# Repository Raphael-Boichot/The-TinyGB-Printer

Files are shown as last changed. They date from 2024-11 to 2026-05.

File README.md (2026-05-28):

# The TinyGB Printer - A standalone Game Boy Printer emulator with a fancy display

The TinyGB Printer is the simplest possible Game Boy printer emulator storing images directly on SD card. This is basically a demake of the ESP32 based [NeoGB printer](https://github.com/zenaro147/NeoGB-Printer) (which I co-developed with [Rafael Zenaro](https://github.com/zenaror), based on the emulator platform casted by [Brian Khuu](https://github.com/mofosyne)), but for the Raspberry Pi Pico. It stores the printed images in pixel perfect 4x PNG format. It is meant to be powered by double NiMH AA or AAA batteries, like the Game Boy Color / Pocket, so that you can recharge them with the same equipment. All parts are cheap and easy to gather online and assembly is meant to be simplistic.

**It supports all printing modes of all games compatible with the Game Boy Printer (with all possible protocol tricks like double speed, compression, custom palette, break command, arbitrary lenght printing, etc.).** So yes, all Pokémons, Link's Awakening DX, Super Mario Bros Deluxe, Game Boy Camera, all work, plus dozens of other ones. This emulator of course works with any genuine model of Game Boy (DMG, GBC, GBP, GBA). Compatibility was also confirmed with the third-party [GB Boy Colour](https://github.com/Raphael-Boichot/Knowledge-repo-about-the-Kong-Feng-GB-BOY-COLOUR) and Analogue Pocket devices.

You can copy, modify, or improve it as you wish, all sources are provided. **Just respect the license and the dedication of the authors**. In very brief, don't forget to cite Brian KHUU (emulator/parser part) and Raphaël BOICHOT (hardware/decoder part) as authors and give a link to this repository.

You can also share your images with the friendly community of Game Boy Camera enthusiasts on the [Game Boy Camera Club Telegram](https://t.me/gameboycamera). I can also help you solving issues on that Telegram. Just to precise: I do not sell the device, buying parts, making and sending them at a decent price would not cover my working hours.

## Make it, enjoy it !
**Nothing to compile, nothing to install, drop the UF2 file to the device and it works straight after soldering.**
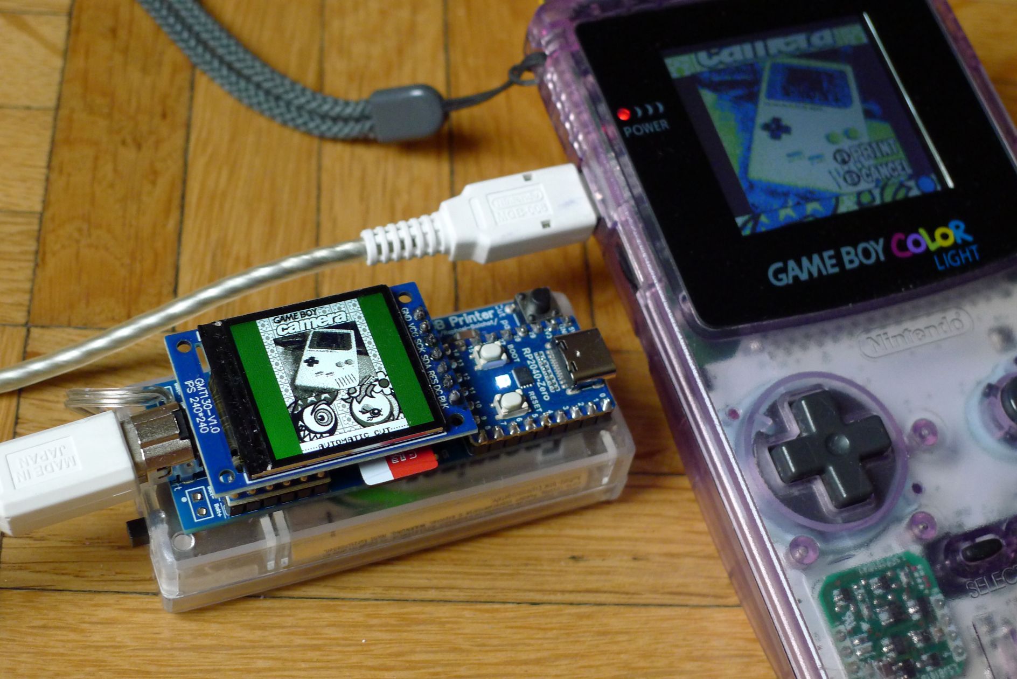
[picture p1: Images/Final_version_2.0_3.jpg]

(Credit: Raphaël BOICHOT)

## What's inside / how does it work ?
The code is basically the [Arduino Game Boy Printer emulator](https://github.com/mofosyne/arduino-gameboy-printer-emulator) (with a bit of tuning to handle the Pi Pico SDK commands) running on core 0 and a custom image decoder running on core 1 in parallel. Good timing between the two cores is critical (and required quite a lot of optimisation) as core 0 cannot miss any single interrupt while core 1 must fulfill all its tasks on time with a good safety margin. Flux control to "occupy" the Game Boy during image conversion is not necessary here.

## Easy to install
- After soldering everything, connect the Raspberry Pi Pico with a USB cable to your computer while pressing BOOT, drop the [uf2 file](/Builds) to the USB folder poping out and enjoy your device. If it makes smoke, check for shorts with a multimeter.
- **Only** if you want to modify the code and recompile it, use the [Arduino IDE](https://www.arduino.cc/en/software) equipped with the [RP2040 core for Arduino IDE](https://github.com/earlephilhower/arduino-pico). Then from the Arduino library manager install the [PNGEnc library](https://github.com/bitbank2/PNGenc), the [Bodmer TFT_eSPI libray](https://github.com/Bodmer/TFT_eSPI) and the [Adafruit Neopixel for Arduino IDE](https://github.com/adafruit/Adafruit_NeoPixel), [configure libraries](/TinyGB_Printer/TFT_setup) and choose the Raspberry Pi Pico target before compiling with default parameters (@200 MHz). I used the Arduino IDE because it gives a very user-friendly access to dev on RP2040 core without too much limitations. And the Earle Philhower RP2040 core is damn good too, it contains everything you need, tons of commented examples and ultra reactive support.

## Easy to use
- 🟢 Power the device without touching anything, the LED flashes green (display backround is green too), images are recorded and sliced automatically, this is the **automatic mode**. This is perfect for the Game Boy Camera for example. Multi-print is of course supported. It uses protocol after margins to decide wether an image is finished or not.
- 🔵 Power while pressing the pushbutton : the LED flashes blue (display backround is blue too), all images are stacked together in a single file until you press the pushbutton again to "cut paper", it's the **tear mode**. Some rare games require this (see complete game list). You can also use it freely to stack images in some other games. Just be creative !
- :red_circle: Power the device and the LED blinks red on and off in cycle: SD card not connected or not formatted in FAT32. SD card can be inserted during this step, the device will then boot normally.
- :repeat: Cycling the power switch on the battery box or using the RESET button on the board has the same effect (reset printer state and increase folder number with the regular build).

A new folder is created at each boot/RESET. Each image file has a unique ID. Flashes during printing indicate flux of data and access to SD card. Color of flashes indicates the mode (green for automatic mode, blue for tear mode). White dim LED indicates that the device is idle and ready to receive data (and that you forgot to switch it off after printing), in case you chose not using the display.

If you miss the analog feeling of thermal paper, you can still use this [thermal printer emulator](/SD/Paper_emulator) written in GNU Octave which turns your pixel perfect images into noisy paper strips with an exact aspect ratio and paper tone compared to a real Game Boy Printer equiped with genuine color / white paper. At least these will not fade with time !

**There is also an easter egg, will you find it ?** (Easy for real camera / printer nerds)

## Easy to fabricate
All the parts used here are cheap and easy to find on Aliexpress. You probably yet have some leftovers from other projects. The total price is probably well below 15€ per unit (being pessimistic), shipping of parts included, and you will have extra parts to gift some to your nerdy friends.

**Parts to order:**
- [The PCB](/PCB_2.0_with_TFT/). Order at [JLCPCB.com](https://jlcpcb.com/) (just drop the gerber .zip to the site and use default options). VAT is paid when ordering so no bad surprise for European customers. They also offer worldwide very cheap shipping options. The PCB was designed with [EasyEDA Standard Edition](https://easyeda.com/) if you want to modify something.

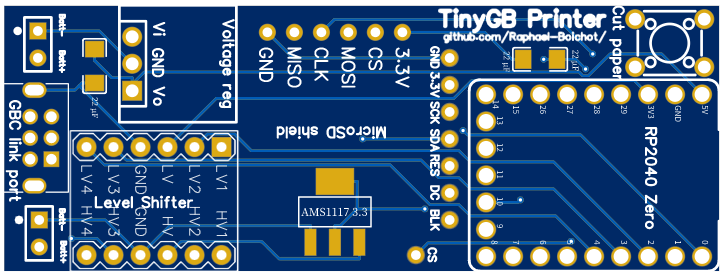
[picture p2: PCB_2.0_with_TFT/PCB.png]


(note the TFT CS pin exposed, just in case, but not used with the display listed next)

The code works with the two PCB versions (1.0 without TFT and 2.0 with TFT) but I recommend ordering only the 2.0 even if you do not plan using the TFT display (just let the pins exposed or soldered with a bare female pin header).

- [A Raspberry Pi Pico Zero](https://aliexpress.com/item/1005007945758255.html). Just check pinout if seller is not the same.
- [A bare MicroSD shield](https://www.aliexpress.com/item/1005005302035188.html) without internal power converter and **without pin header** (the pins header will be mounted upside down compared to pre-soldered units so it must be soldered manually).
- [A 240x240 1.3 inches TFT Display](https://aliexpress.com/w/wholesale-240x240-pixels-7-pins.html). It must be that exact one, 7 pins, without CS, 240x240 pixels, GMT130-V1.0 (now often IPS 240x240 apparently). If you decide to use another 240x240 pixels model, CS pin is exposed and driven but it's up to you to reconfigure the TFT library if necessary.
- [A 4 gates level shifter](https://www.aliexpress.com/item/1005006255186878.html). The Pi Pico pins are not 5V rated, so the need for a level shifter. They are highly reusable in other pico related projects, so you never have too much of them in spare. If the ones you received [look like this](https://forum.arduino.cc/t/logic-level-shifter-problem/1138650?page=2), ask for refund, they are fake / defective.
- [A 5V DC-DC step-up converter](https://www.aliexpress.com/item/32809095271.html), 0.9-5V (input) to 5V (output). I know, it does not look impressive but it does perfectly the job of powering small devices. If you want the blue fullset, they sometimes appear with blus PCB.
- [Male and female pin headers](https://www.aliexpress.com/item/4000873858801.html) with 2.54 mm spacing, whatever the pin lenght, you will trim them anyway. The female pin header is required for the TFT display only. Once again, highly reusable in other projects.
- [A GBA/GBC external link port](https://www.aliexpress.com/item/1005006358075502.html). They can be cheap or not depending on the seller, do not hesitate to change. This port is for the Gameboy Advance but it's backwards compatible (with the right cable) with any model of Game Boy.
- [A 6x6 mm pushbutton](https://www.aliexpress.com/item/1005003938244847.html), whatever height. The softer the better if you have the choice. Make sure you get the 4 pins version with the short legs.
- [2 x 22 µF caps with a 1206 footprint](https://www.aliexpress.com/item/1005006022131059.html) (22 to 50 µF is OK if you have spares). Take 10V or 16V. These come in packs of 20, you only need 2, so check your drawers just in case.
- An [AMS1117-3.3V converter](https://www.aliexpress.com/item/4001104149446.html) - Beware, take the 3.3V, not the ADJ !
- A [2xAA](https://www.aliexpress.com/item/4000980371784.html) or [2xAAA](https://www.aliexpress.com/item/1005004195965365.html) battery box **with switch** (mandatory, this is the only way to switch the device on and off). Single AA or AAA battery is too weak to power the device reliably. The choice of AA or AAA depends on which is your go to Game Boy (pocket or GBC), in order to recharge batteries by batch of 4.

Additionnaly, you would need a [GBC compatible link cable](https://www.aliexpress.com/item/1005006479007710.html). Beware, purple GBA cables (or specific GBA cables) are not compatible due to a different pinout. You can of course use genuine GBC/GBP link cables or DMG link cable with GBC/GBP adapter.

**How to make it:**
- Solder the pin headers on the Pi Pico, the SD shield, the level shifter and the step-up converter. **Beware of which side you solder the pin header**. Check if you can drop the uf2 file to the Pico, it must blink red on and off, it's normal.
- Solder the caps and the 3.3V converter first. They are surface mount components but big enough to be soldered easily. Don't be afraid by their size. They are not tiny, you're just too far.
- Solder all parts with the minimal clearance possible against the PCB.
- The TFT display can be mounted on female pin headers at this step but display is fully optional. The device works without !
- Trim and reflow all pins on the back side to get a clean finish. I personally trim pins as short as possible before soldering but there is a risk of scratching the solder mask, so be carefull.
- Clean as much as you can any flux residues with isopropanol. Flux may create parasitic noise between pins. **Beware, flushing the TFT display with isopropanol is a very reliable way of killing it !**
- Solder the battery box terminals and stuck the PCB on it with double sided tape for example (or hot glue if you're addicted to hot snot like me).
- You're ready to print !

The device can record a little more than 1 standard Game Boy Camera image for each mAh of battery storage capacity, so about 800 images with 2xAA batteries and about 2500 images with 2xAA batteries on a single charge (TFT display connected). Not connecting the TFT display would allow about 30% more images to be recorded on a single charge.

**The TinyGB Printer assembled without display (TFT display is optional) and 2xAAA battery box**
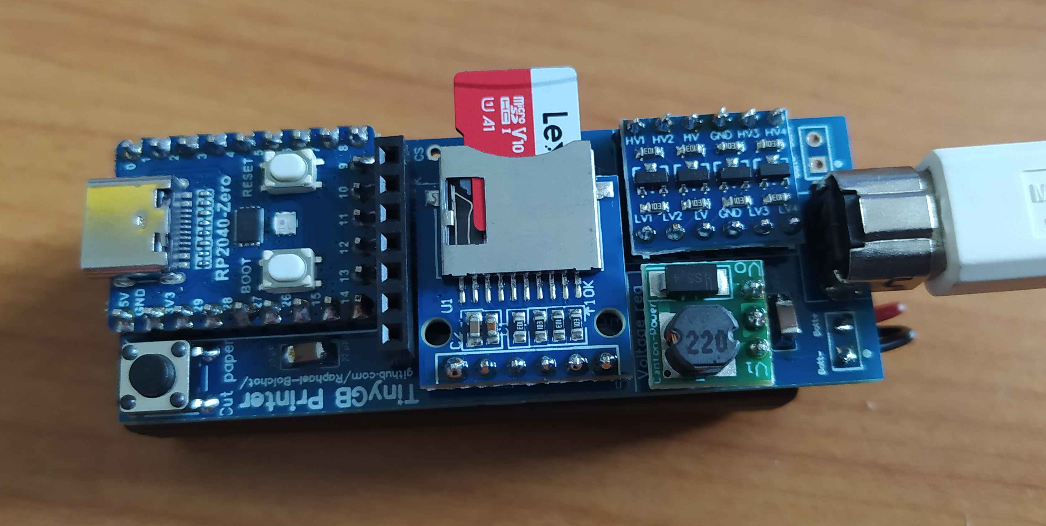
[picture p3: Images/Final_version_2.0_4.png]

(Credit: Raphaël BOICHOT)

**The TinyGB Printer assembled with a 2xAA battery box and the TFT display compared to the 2xAAA / no TFT setup**
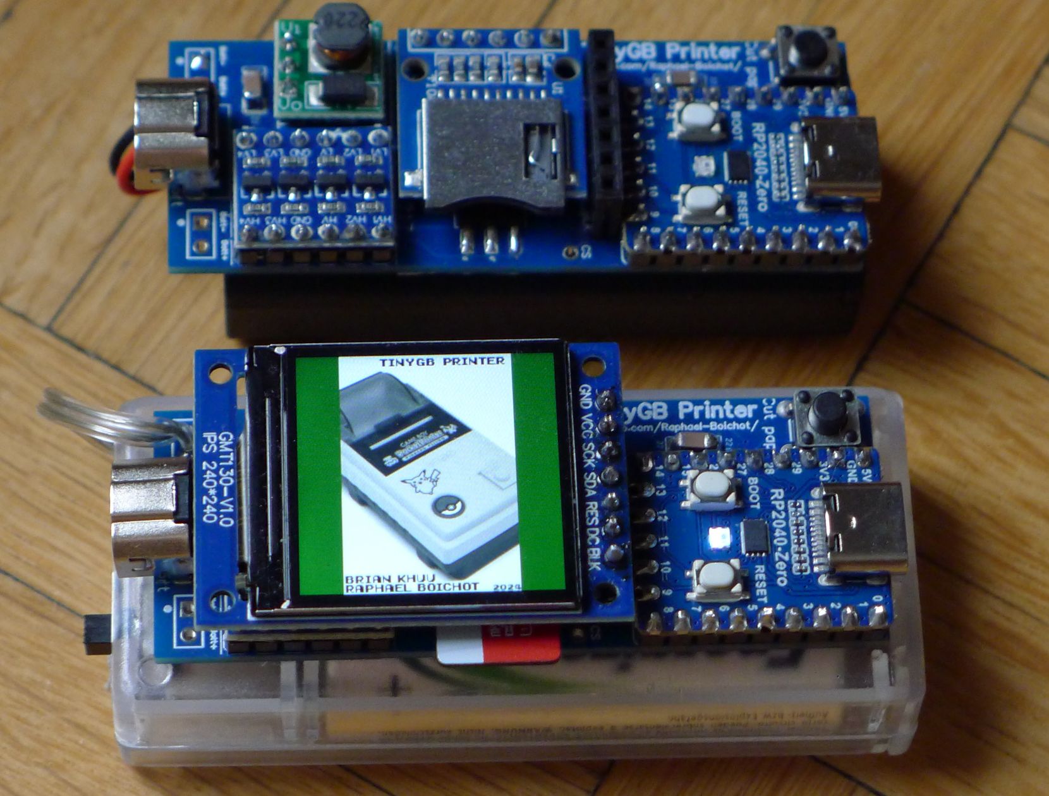
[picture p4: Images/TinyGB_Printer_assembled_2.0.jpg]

(Credit: Raphaël BOICHOT)

**The TinyGB Printer with TFT display and [3D printed case](/PCB_2.0_with_TFT/3D_printed_enclosure)**
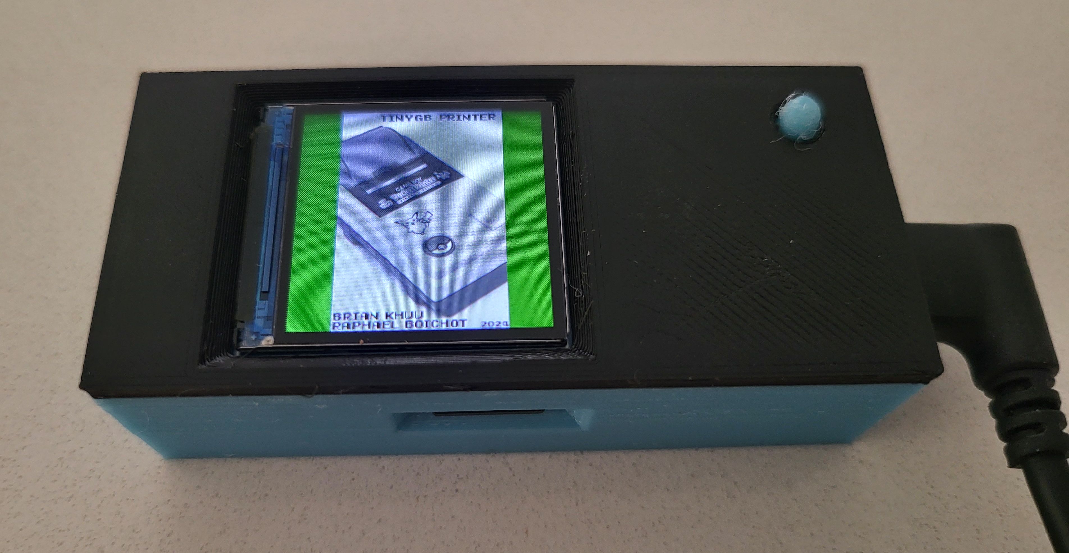
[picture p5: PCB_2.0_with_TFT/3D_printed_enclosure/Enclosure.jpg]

(Credit: Slade1972)

**Troubleshooting**
- Last image is not written or image file is broken ? You've probably switched the device off during the PNG encoding or you forgot to tear paper with the pushbutton in tear mode.
- The TFT display does not work when you compile by yourself ? See [notes](https://github.com/Raphael-Boichot/The-TinyGB-Printer/blob/f55e4003a29216d7775f089cb41b405cfadc126f/TinyGB_Printer/TinyGB_Printer.ino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) for configuring the TFT_eSPI library, you have to manually edit some command for this very particular display.
- Any SD card must work out of the box, even old/slow ones. If the printer is reluctant to recognize yours, use a [low level formatting tool](https://www.sdcard.org/downloads/formatter/) or low level formatting commands like diskpart on Windows. Filesystem must be FAT32.
- The image palette is obviously wrong for a particular game ? Open an issue and I will rapidely find a solution.

## Examples of use

### Save your achievements and diploma
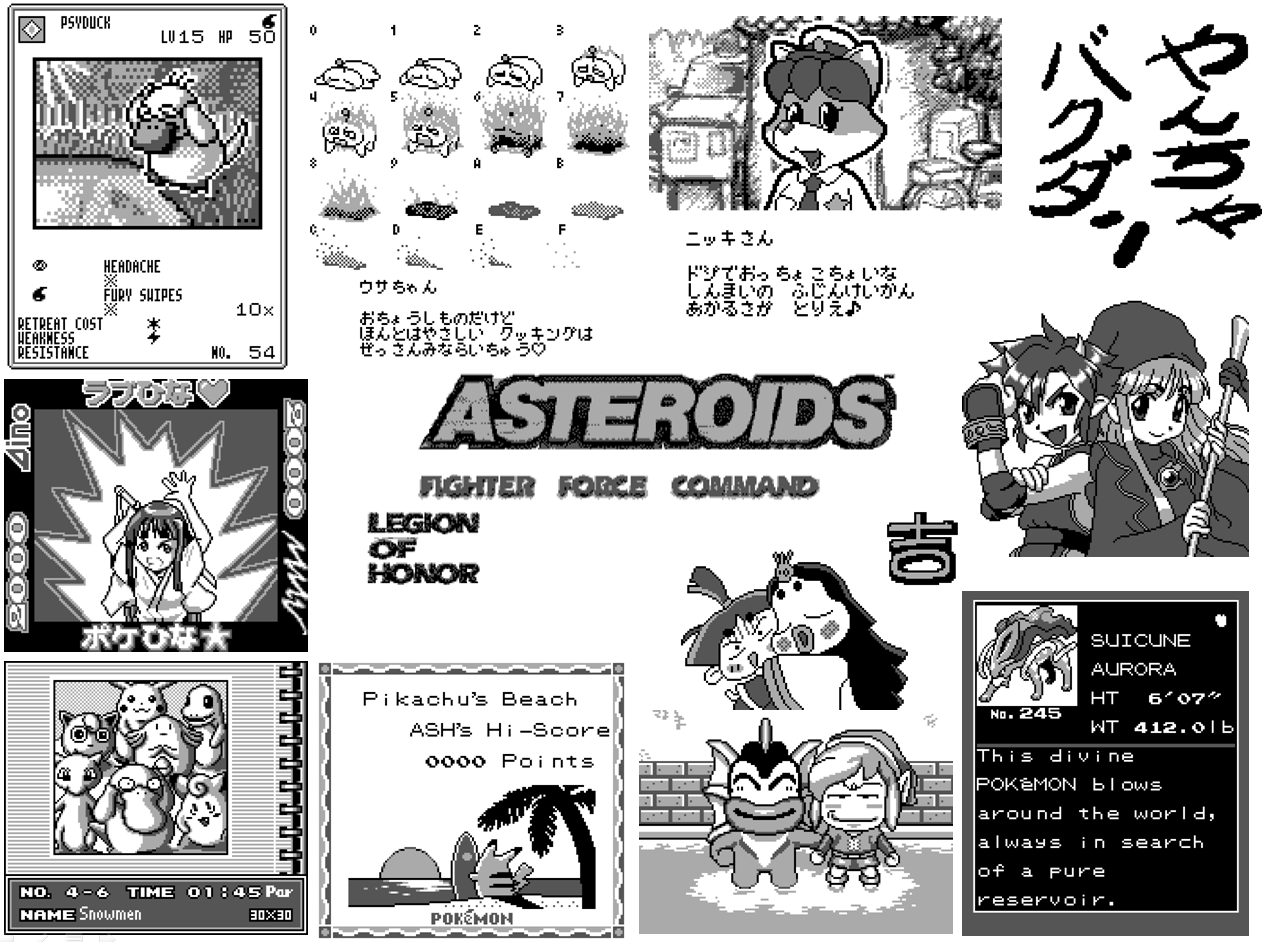
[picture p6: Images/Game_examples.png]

(yes I suck at Surfing Pikachu)

### Save your preferred Game Boy Camera images
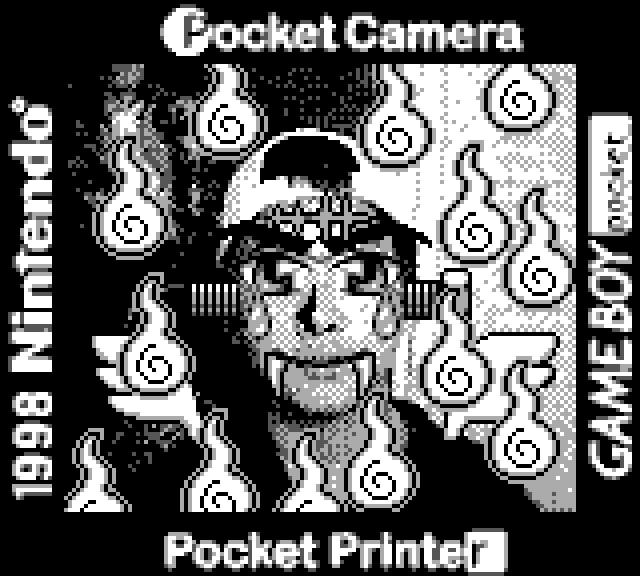
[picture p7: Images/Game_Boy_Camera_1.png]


### Make fancy timelapses with [photo!](https://github.com/untoxa/gb-photo) (requires a [flashable camera](https://github.com/Raphael-Boichot/Game_Boy_Mini_Flashable_Camera) and a [script](/SD/Script_for_animated_gif))


(Credit: Raphaël BOICHOT)

### Make [High Dynamic Range](/SD/Scripts_for_AEB_mode) image with [photo!](https://github.com/untoxa/gb-photo) (requires a [flashable camera](https://github.com/Raphael-Boichot/Game_Boy_Mini_Flashable_Camera))
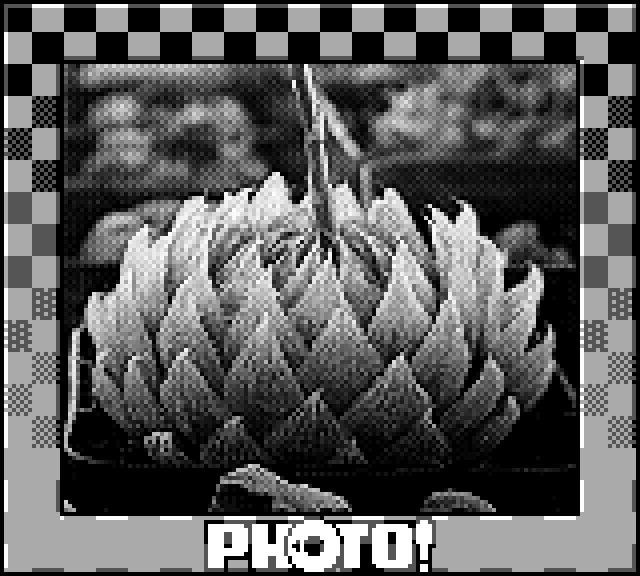
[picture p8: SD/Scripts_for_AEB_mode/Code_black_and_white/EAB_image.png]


(Credit: Raphaël BOICHOT)

### Make color images using RGB filters and [script for stacking](/SD/Scripts_for_AEB_mode) (requires a PC)
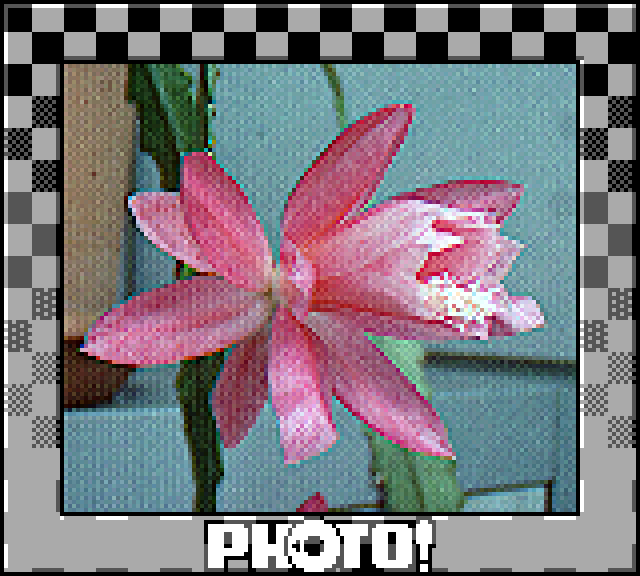
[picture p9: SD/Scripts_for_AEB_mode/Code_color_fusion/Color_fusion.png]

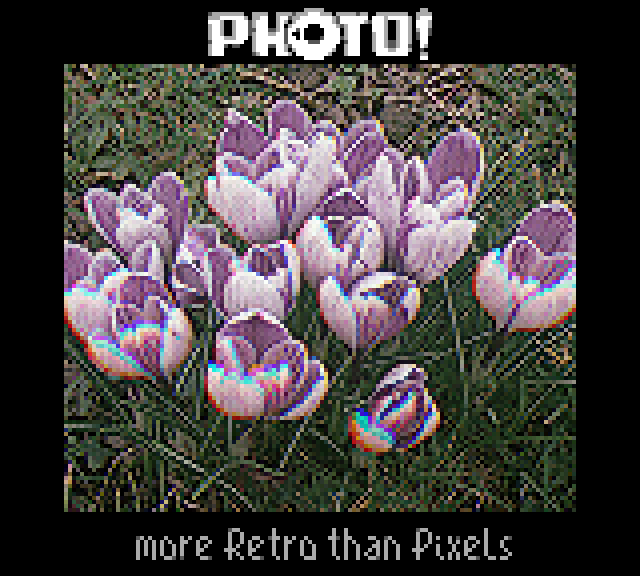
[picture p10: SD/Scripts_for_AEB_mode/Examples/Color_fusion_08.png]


(Yes, this is done with a Game Boy Camera)

Besides scripts proposed here, you can also upload your images to the [GBCamera Android Manager](https://github.com/Mraulio/GBCamera-Android-Manager) or use the [Python HDR image processing tool](https://github.com/seb-tourneux/gbcam-hdr-utils) and apply the exact same process.

### Simulate thermal paper output with a [dedicated script](/SD/Paper_emulator)
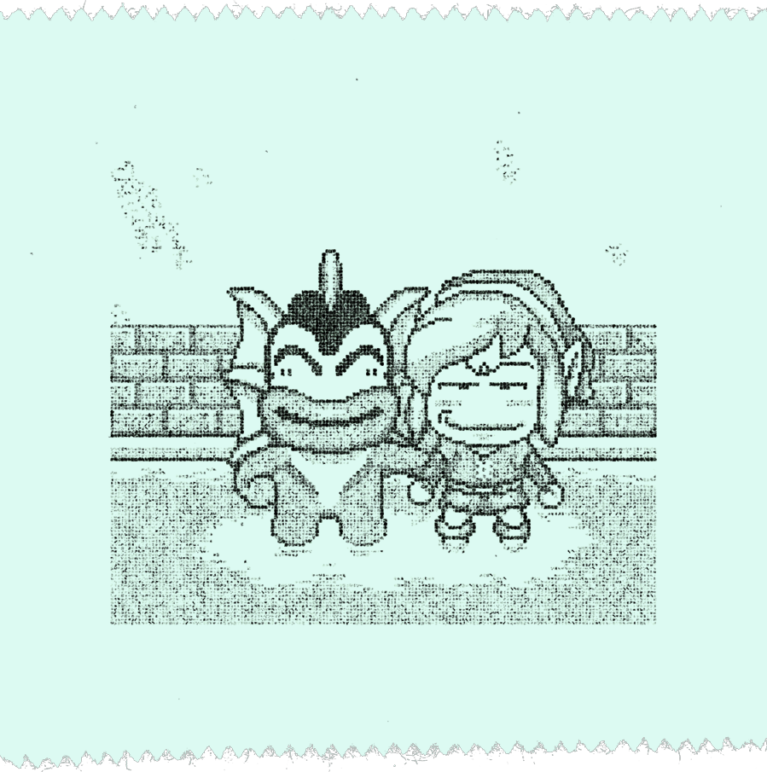
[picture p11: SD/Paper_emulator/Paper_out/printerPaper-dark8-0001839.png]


## Compatible with the 110 original games using the Game Boy Printer
In *Italics* games working fine in automatic mode, in **bold** games requiring the push button to tear paper, or tear mode. For who wonders if I'm crazy, after initially documenting the complete list (I hope) in sweat and blood around 2021, I've tested ALL these games and save hacked several dozens of them to access and test all cryptic printing features, took me months (most are in Japanese, many are [kusoge](https://en.wikipedia.org/wiki/Kusoge)).

- *1942*
- *Alice in Wonderland (US version only, Euro version not printer compatible)*
- *Animal Breeder 3 (あにまるぶりーだー3)*
- *Animal Breeder 4 (あにまるぶり〜だ〜4)*
- *Aqualife (アクアライフ)*
- *Asteroids*
- *Austin Powers: Oh, Behave!*
- *Austin Powers: Welcome to My Underground Lair!*
- *Austin Power Episode 3 - Yeah Baby Yeah (leaked, rom CGBBA3P0.3)*
- *Austin Power Episode 4 - Why Make Millions (leaked, rom CGBBA4P0.0)*
- *Cardcaptor Sakura: Itsumo Sakura-chan to Issho! (カードキャプターさくら 〜いつもさくらちゃんと一緒〜)*
- *Cardcaptor Sakura: Tomoe Shōgakkō Daiundōkai (カードキャプターさくら 〜友枝小学校大運動会〜)*
- *Chee-Chai Alien (ちっちゃいエイリアン)*
- *Cross Hunter - Monster Hunter Version (クロスハンター モンスター・ハンター・バージョン)*
- *Cross Hunter - Treasure Hunter (クロスハンター トレジャー・ハンター・バージョン)*
- *Cross Hunter - X Hunter Version (クロスハンター エックス・ハンター・バージョン)*
- *Daa! Daa! Daa! Totsuzen ★ Card de Battle de Uranai de!? (だぁ!だぁ!だぁ! とつぜん★カードでバトルで占いで!?)*
- *Daikaijuu Monogatari: The Miracle of the Zone II (大貝獣物語 ザ・ミラクル オブ ザ・ゾーンII)*
- *Dejiko no Mahjong Party (でじこの麻雀パーティー)*
- *Densha de GO! 2 (電車でGO!2)*
- *Dino Breeder 3 - Gaia Fukkatsu (ディノブリーダー3 〜ガイア復活〜)*
- *Disney's Dinosaur*
- *Disney's Tarzan (ディズニーズ ターザン) - The game has a palette error fixed by the printer*
- *Donkey Kong Country (ドンキーコング2001)*
- *Doraemon Kart 2 (ドラえもんカート2)*
- *Doraemon Memories - Nobita no Omoide Daibouken (ドラえもんメモリーズ のび太の想い出大冒険)*
- *Doraemon no Game Boy de Asobouyo Deluxe 10 (ドラえもんのGBであそぼうよ デラックス10)*
- *Doraemon no Quiz Boy (ドラえもんのクイズボーイ)*
- *Dungeon Savior (ダンジョンセイバー)*
- **E.T.: Digital Companion**
- *Fairy Kitty no Kaiun Jiten: Yousei no Kuni no Uranai Shugyou (フェアリーキティの開運辞典 妖精の国の占い修行)*
- *Fisher-Price Rescue Heroes: Fire Frenzy*
- *Game Boy Camera or Pocket Camera (ポケットカメラ)*
- *Golf Ou: The King of Golf (ゴルフ王)*
- *Hamster Club (ハムスター倶楽部)*
- *Hamster Paradise (ハムスターパラダイス)*
- *Hamster Paradise 2 (ハムスターパラダイス2)*
- *Harvest Moon 2 (牧場物語GB2)*
- *Hello Kitty no Beads Koubou (ハローキティのビーズ工房)*
- *Hello Kitty no Magical Museum (ハローキティのマジカルミュージアム)*
- *Hello Kitty Pocket Camera (ハローキティのポケットカメラ, leaked, rom GBDHKAJ0.2)*
- *Jinsei Game Tomodachi takusan Tsukurou Yo! (人生ゲーム 友達たくさんつくろうよ!)*
- *Kakurenbo Battle Monster Tactics (モンスタータクティクス)*
- *Kanji Boy (漢字BOY)*
- *Karamuchou wa Oosawagi!: Porinkiis to Okashina Nakamatachi (カラムー町は大さわぎ! 〜ポリンキーズとおかしな仲間たち〜)*
- *Karamuchou wa Oosawagi!: Okawari! (カラムー町は大さわぎ！おかわりっ！)*
- *Kaseki Sousei Reborn II: Monster Digger (化石創世リボーン2 〜モンスターティガー〜)*
- *Kettou Transformers Beast Wars - Beast Senshi Saikyou Ketteisen (決闘トランスフォーマービーストウォーズ ビースト戦士最強決定戦)*
- *Kidou Senkan Nadesico - Ruri Ruri Mahjong (機動戦艦ナデシコ ルリルリ麻雀)*
- *Kisekae Monogatari (きせかえ物語)*
- *Klax*
- *Konchuu Hakase 2 (昆虫博士2)*
- *Little Nicky*
- *Logical*
- *Love Hina Pocket (ラブ ひな)*
- *Magical Drop*
- **Mary-Kate and Ashley Pocket Planner**
- **McDonald's Monogatari : Honobono Tenchou Ikusei Game (マクドナルド物語)**
- *Mickey's Racing Adventure*
- *Mickey's Speedway USA*
- *Mission: Impossible*
- *Monster ★ Race 2 (もんすたあ★レース2)*
- *Monster ★ Race Okawari (もんすたあ★レース おかわり)*
- *Nakayoshi Cooking Series 1 - Oishii Cake-ya-san (なかよしクッキングシリーズ1 おいしいケーキ屋さん)*
- *Nakayoshi Cooking Series 2 - Oishii Panya-san (なかよしクッキングシリーズ2 おいしいパン屋さん)*
- **Nakayoshi Cooking Series 3 - Tanoshii Obentou (なかよしクッキングシリーズ3 たのしいお弁当)**
- **Nakayoshi Cooking Series 4 - Tanoshii Dessert (なかよしクッキングシリーズ4 たのしいデザート)**
- **Nakayoshi Cooking Series 5 - Cake Wo Tsukurou (なかよしクッキングシリーズ5 こむぎちゃんのケーキをつくろう!)**
- *Nakayoshi Pet Series 1: Kawaii Hamster (なかよしペットシリーズ1 かわいいハムスタ)*
- *Nakayoshi Pet Series 2: Kawaii Usagi (なかよしペットシリーズ2 かわいいウサギ)*
- *Nakayoshi Pet Series 3: Kawaii koinu (なかよしペットシリーズ3 かわいい仔犬)*
- *NFL Blitz*
- **Nintama Rantarou GB: Eawase Challenge Puzzle (忍たま乱太郎GB えあわせチャレンジパズル)**
- *Ojarumaru: Mitsunegai Jinja no Ennichi de Ojaru! (おじゃる丸 〜満願神社は縁日でおじゃる!)*
- *Pachinko Data Card - Chou Ataru-kun (Pachinko Data Card ちょ〜あたる君〜)*
- *Perfect Dark*
- *Pocket Family 2 (ポケットファミリーGB2)*
- *Pocket Kanjirou (ポケット漢字郎)*
- *Pocket Puyo Puyo-n (ぽけっとぷよぷよ〜ん)*
- *Pokémon Card GB2: Great Rocket-Dan Sanjō! (ポケモンカードGB2 GR団参上!)*
- *Pokémon Crystal (ポケットモンスター クリスタルバージョン)*
- *Pokémon Gold (ポケットモンスター 金)*
- *Pokémon Picross (ポケモンピクロス, leaked, rom DMGAKVJ0.1)*
- *Pokémon Pinball (ポケモンピンボール)*
- *Pokémon Silver (ポケットモンスター 銀)*
- *Pokémon Trading Card Game (ポケモンカードGB)*
- *Pokémon Yellow: Special Pikachu Edition (ポケットモンスター ピカチュウ)*
- *Pro Mahjong Tsuwamono GB (プロ麻雀兵 GB)*
- *Purikura Pocket 3 - Talent Debut Daisakusen (プリクラポケット3 〜タレントデビュー大作戦〜)*
- *Puzzled*
- *Quest for Camelot*
- *Roadsters Trophy*
- *Sanrio Timenet: Kako Hen (サンリオタイムネット 過去編)*
- *Sanrio Timenet: Mirai Hen (サンリオタイムネット 未来編)*
- *Shinseiki Evangelion Mahjong Hokan Keikaku (新世紀エヴァンゲリオン 麻雀補完計画)*
- *SMARTCOM (requires a hack to bypass boot sequence)*
- *Sōko-ban Densetsu: Hikari to Yami no Kuni (倉庫番伝説 光と闇の国)*
- *Super Black Bass Pocket 3 (スーパーブラックバスポケット3)*
- *Super Mario Bros. Deluxe (スーパーマリオブラザーズデラックス)*
- *Sweet Angel (スウィートアンジェ)*
- *Sylvanian Families: Otogi no Kuni no Pendant (シルバニアファミリー 〜おとぎの国のペンダント〜)*
- *Sylvanian Families 2 - Irozuku Mori no Fantasy (シルバニアファミリー2～色づく森のファンタジー)*
- *Sylvanian Families 3 - Hoshi Furu Yoru no Sunadokei (シルバニアファミリー３　星ふる夜のすなどけい)*
- *Tales of Phantasia: Nakiri's Dungeon (テイルズ オブ ファンタジア なりきりダンジョン)*
- *The Legend of Zelda: Link's Awakening DX (ゼルダの伝説 夢をみる島DX)*
- *The Little Mermaid 2: Pinball Frenzy*
- *Tony Hawk's Pro Skater 2*
- *Trade & Battle: Card Hero (トレード&バトル カードヒーロー) - The game has a palette error fixed by the printer*
- *Tsuri Sensei 2 (釣り先生2)*
- *VS Lemmings (VS.レミングス) - Lemmings US version does not have print feature*

Want to know more about these games ? Want hints and custom saves to unlock all printing features ? Want to read the whole story of the thermal printer emulator module ? Follow the [link](https://github.com/Raphael-Boichot/GameboyPrinterPaperSimulation).

## Also compatible with homebrews known to work with the Game Boy Printer
In *Italics* games working fine in automatic mode, **in bold** games requiring the push button to tear paper, or tear mode.

- *[2bit PXLR Studio](https://github.com/HerrZatacke/2bit-pxlr-studio) by Andreas Hahn - The first Game Boy Camera custom rom*
- *[Photo!](https://github.com/untoxa/gb-photo) by Untoxa - A Game Boy Camera custom rom, evolution of 2bit PXLR Studio*
- *[gb_snake](https://github.com/reini1305/gb_snake) by Christian Reinbacher - A one or two players version of Snake*
- **[gb_bannerprinter](https://github.com/reini1305/gb_bannerprinter) by Christian Reinbacher - A thermal paper banner printer**
- *[Blarble1290](https://8bittygames.com/blarble1290/) by Patrick Rodriguez - A text based adventure where the printer talks to you, miserable human being !*
- *A [Game Boy Printer test rom](https://github.com/mmuszkow/gbprinter) by Maciek Moszkowski - It prints text to the printer, what else ?*
- **[GBC Windows](https://archive.org/details/gbcwindows) by Rubenretro, developped with GB Studio - A spoof of Windows 3.1 with a printer function that works, mostly.**

If you find any homebrew **working for real on a genuine Game Boy Printer** (not a PC emulator please) and **not working on the TinyGB Printer**, create an issue, I will support it soon. Besides that, I'm not interested in supporting homebrews or printing modes not fully compatible with real hardware (I made an exception with Blarble1290 because it is fun to play, see the "Funfacts" section).

## Documented limitation
- [Photo!](https://github.com/untoxa/gb-photo) standard printing (normal speed and double speed) is the only mode supported to date. Fast Printing and Transfer modes are only supported by the [Pico GB Printer](https://github.com/untoxa/pico-gb-printer), a very good dedicated printer emulator. You can directly play with it by just flashing the [last release](/Builds) compiled for the current board, it's directly compatible (just drop it to the Pi-Pico and follow the instructions).
- After tens of thousands of images stored, the access to SD card can become unstable and multi-print may crash within a session. The device just reminds you that embedded systems and FAT32 formatting are not expected to manage such enormous number of file. It's probably time to move your precious files on a more durable medium anyway.

## Dev notes
- The Pi Pico zero is not able to power the SD card (in writing mode) and keep track of the interrupts with the serial port at the same time, so the separate 3.3V regulator for the SD shield. The 5V step-up converter itself is also rather noisy, so extra caps are necessary. Keeping the SD card alive in writing mode is surprisingly power hungry.
- The 5 volts line is mandatory for the level shifter so I found easier to power everything from it but it's a design choice. It also eases powering the device with a powerbank or an OTG cable from USB. In brief it is more versatile.
- The [DC-DC converter](/Images/DC_DC_characteristics.png) allows in theory using from 1 to 4 NiMH batteries. The bottleneck is when the current peaks during SD card access in write mode. If voltage drops below a critical level (about 2.7V instead of 3.3V) during this phase, even briefly, the file is just discarded without warning. 2 cells is a good reliability / bulkiness compromise from my own experience but 3 to 4 would allow going farther in the discharge curve. One single cell is just not an option (it will print 10-15 images consecutively and discard the next ones until the next reboot, which is not very handy). The device can of course run with 2 regular alkaline batteries, even pretty depleted, in case of emergency.
- The device does not keep track of date/time and won't, even in the future (same for the camera anyway, so what's the point ?). If this is a very critical feature for you, better use another device. Adding a RTC module complicates the design and the code for a very small added value. The idea here is to be (and stay) as minimalistic as possible. I've anyway added some Powershell script to do this from your preferred OS.
- Feel free to make a lithium battery powered design of your dream. Lithium batteries are not recycled, baroque in size / formats and they are prone to become [spicy pillows](https://www.reddit.com/r/spicypillows/) after some time of storage without use, whatever the conditions. I don't like them. I want my devices to be stored _easily_ without batteries if necessary. You can directly power the current board from a dedicated subboard outputting 5V via the battery pads, the 5V voltage converter can accept 5V as input without problem.
- The emulator part features no flux control (no need) apart from sending a fixed number of "busy" commands to the Game Boy (basically 1 just in case in the last release), as the image decoder running on core 1 is independent from the emulator running on core 0. The decoder must just be fast enough to be always available when called from core 0. Technically, converting a standard 160x144 pixels image from Game Boy Tile Format in memory (5760 bytes) to a compressed and indexed 640x576 pixels PNG image written on SD card takes approximately 0.5 seconds. The (near) blink of an eye compared to the real Game Boy Printer.
- I have considered the dev achieved when the device became more reliable than a BitBoy in endurance tests (because even a BitBoy can crash when abused for long in double speed mode) while having extended functions.
- The inspiration came from the experience of co-developping both the hardware and software of the NeoGB Printer on ESP32 with Rafael Zenaro. After four years tinkering with other projects in electronics and helping people to painfully compile, build and configure the NeoGB Printer, I have to admit that the system had some teething problems. The TinyGB Printer was made to be simple, reliable, no Wifi, easy to maintain.
- The device uses a quite baroque 7 pins 240x240 TFT display without CS pin. This is just because I had this one in stock as leftover from another project during dev. It is also very tiny and cute. This display is hopefully quite common on Aliexpress but on the other hand requires some annoying tuning of the TFT library (which in return prevents very efficiently people to alter the design ^_^). The project PCB and code can be easily modified to handle more classical TFT display.

## Funfacts
- Most games do not implement the BREAK command to abort printing but just stop transmission and relies on the very severe timing of the real printer which automatically rejects data packets with dubious dead times in between (more than 150 ms dead time between packets "kills" the whole transmission) or with incorrect checksum. The TinyGB printer detects both BREAK command and dubious packets to reject print.
- Two games have an erroneous palette with DG and LG inverted (Disney's Tarzan and Trade & Battle: Card Hero). By chance, they both use, on purpose, a weird palette not shared by any other game (maybe this explain the issue...) that can be easily detected and fixed automatically by the printer emulator. This palette issue is barely visible with an actual printer but very obvious with a printer emulator (4x pixel perfect upscaling does not lie).
- All genuine games use single packets of 640 bytes as payload for the printer (natural size to print with one pass of the printer head which is 16 pixels high) but data packets could be of any size as long as the sum of bytes transmitted is multiple of 640 in printer memory when the print command is received. A unique homebrew uses single packets of 320 bytes ([Blarble 1290](https://8bittygames.com/blarble1290/)) with print commands in between. A real printer will just refuse to print correctly single packets of 320 bytes, they have to come by two, at least. I guess that Blarble 1290 was tested on emulator only. But the game is fun. So the TinyGB printer was painfully modified to accept this particular weird protocol. Mr Rodriguez, you gave me headaches, in addition to be unreachable on the internet !
- You can still upload the original Arduino Game Boy printer emulator and it will natively work on this board with all its functions ! You will just loose the TFT display / RGB LED support as the original project does not handle the internal LED from the Pi Zero.
- Testing each major code / hardware modification requires tons of quality check in real printing conditions (Game Boy(s), serial cable, batteries, flashcart, sometimes oscilloscope, all that shit). I typically have to pass a dozen of difficult games with ruthless protocol implementation which I know will not print correctly in case of even the slightest issue with printer emulator / decoder. I sometimes try these games on other emulators / decoders for testing their accuracy. Most don't pass this crash test. The TinyGB Printer is the only emulator and decoder combo I know of that is **100% accurate**.
- A noticeable amount of compatible games listed here are considered as the [shittiest GB/GBC games](https://w.atwiki.jp/gcmatome/pages/33.html). I must admit that "playing" some of them (in one case even making a mandatory 100% to just unlock the printer menu) was less enjoyable than a visit to the dentist. I mean some games gave me nausea *systematically* when playing (yes, I'm thinking of you, E.T. The Extra-Terrestrial: Digital Companion, you piece of shit), which is *not always* the case with dental care.

## Running batteryless (at your own risk)
Foreword: SD and VCC are never connected in Game Boy genuine cables nor required by any known Nintendo product. There is no specifications for them contrary to SI and SO which are crossed. It appears that **most after market cables (at least the three I own) have SD and VCC wired AND crossed**. The mod proposed in this section (running batteryless) necessitates after market cables so everything is designed considering that SD and VCC are crossed within the cable.

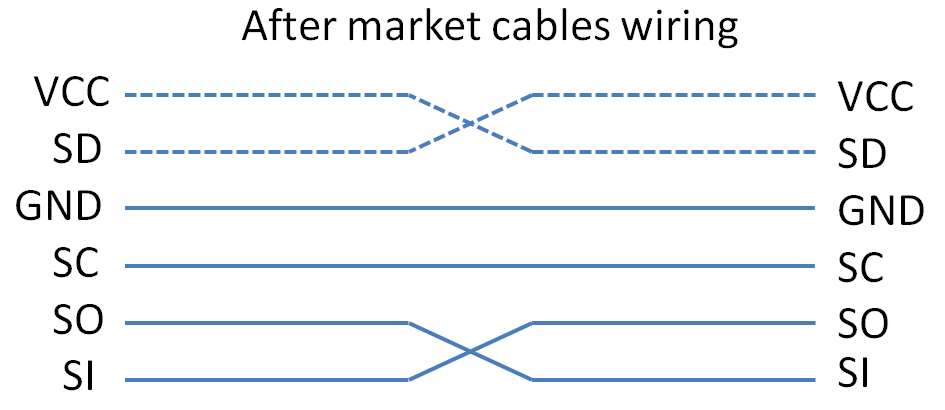
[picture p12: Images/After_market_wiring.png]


Depending on the Game Boy model or flash cartridge you use, it is so possible tu run the device from the +5V (VCC) of the serial port only. For this, I recommend using the TinyGB Printer **without an SD flash cartridge** (so no EZ-FLASH Junior for example). It should put you in a situation where enough juice is available from that poor internal Game Boy power converter.

I recommend using a low forward voltage Shottky diode like a BYV1040 (like here), a 1N5817 or a BAT41 to avoid any fatal connection if the USB is connected as well as the serial. **Cathode must be mounted facing the Pi Pico**. In case of post-assembly, strictly follow the next pictures to see where to connect the +5V.

Now you're ready to run without battery and **at your own risk**. On my side, it works at least on a GBA and a GBC modded with a TFT display, genuine power converter, with different third party cables I own (the transparent green oddity sold on Amazon and the regular black crap from Aliexpress). These are the only tests I've made, you're on your own for your particular display / console combo if it does not work. If connecting the device just crashes your Game Boy, better use to the normal "with battery" setup or try another cable. You can use this [PCB](/PCB_2.0_batteryless/) to play by yourself with this design.

### Retrofit of PCB 2.0 to run batteryless (third party link cable with SD and VCC crossed required)
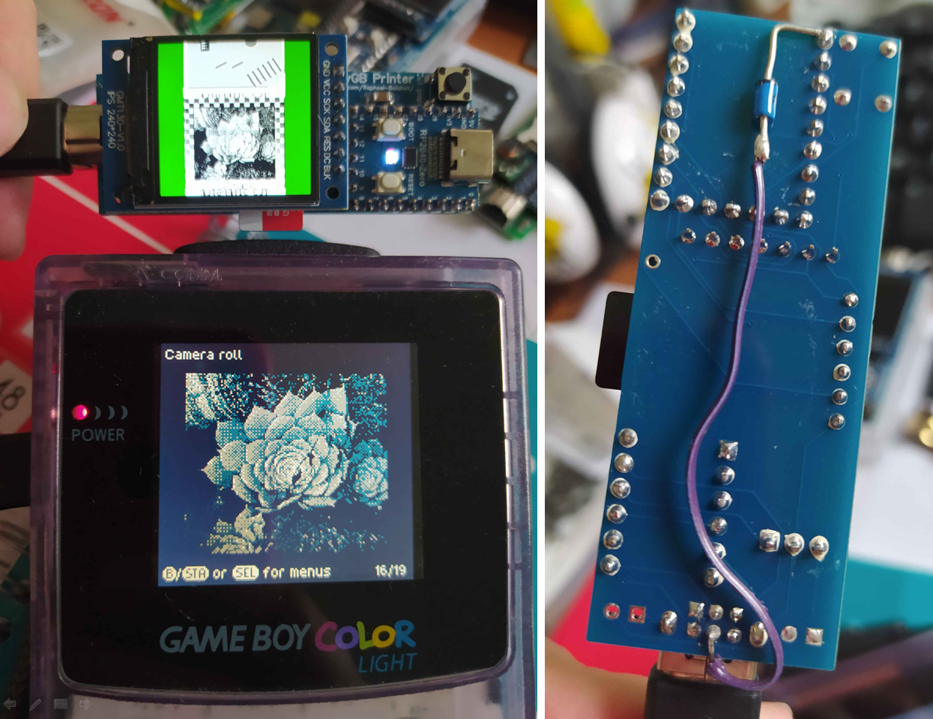
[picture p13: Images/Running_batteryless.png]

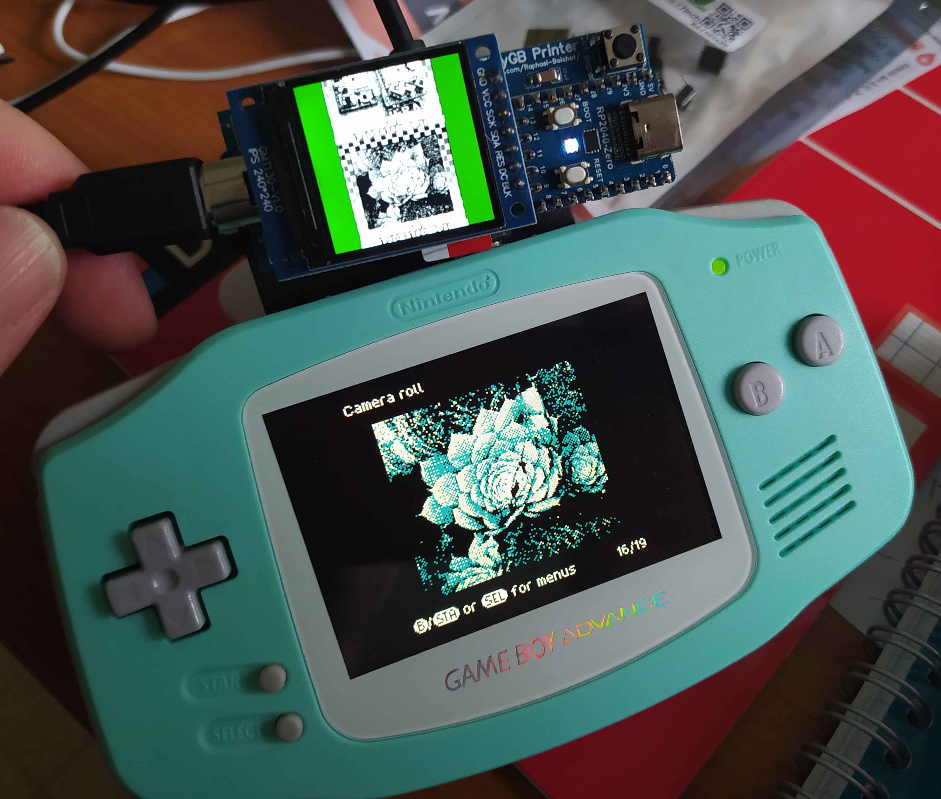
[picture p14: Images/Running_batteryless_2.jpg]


Running from the +5V of the Game Boy, without battery. Note the diode orientation. (Credit: Raphaël BOICHOT)

### Experimental PCB for batteryless mod, just try it !
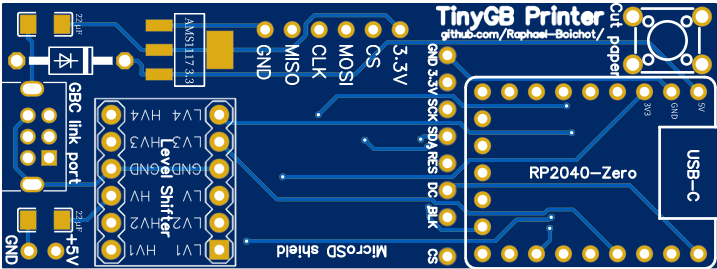
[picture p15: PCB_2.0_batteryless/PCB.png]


Untested, no reason that it would not work. It fits the 3D shell of the PCB V2.0 perfectly as the footprint is exactly the same.

## Kind warning
The code and current design come as is. If you're not happy with the current hardware, the PCB EasyEDA design or the Arduino IDE, create your own, the licence allows it ! Polite pull requests with bulletproof improvements are of course always welcomed. Remind that this project is the fruit of hard work made with dedication, offered for free.

## Acknowledgements
- [Brian Khuu](https://github.com/mofosyne) for the emulator code I have butchered until it accepted to drive my janky core 1 loop. We've worked hard together to support all possible games years ago and he's the true giant whose shoulders I sit on, his emulator is incredibly reliable.
- [Slade1972](https://github.com/Slade1972) for the 3D printed enclosure (PCB 2.0 with display) and feedbacks on the building procedure and thorough compatibility tests with the Analogue Pocket.
- [Björn Heirman](https://github.com/BjornB2) for the 3D printed enclosure (PCB 1.0 without display) and feedbacks on the device ergonomy.
- [Rafael Zenaro](https://github.com/zenaror) for the initial idea ("hey man, why not doing a Pi Pico version of the NeoGB Printer now ?!") and because I reused many chunks of code from the [NeoGB Printer project](https://github.com/zenaro147/NeoGB-Printer). This project is finally more a demake than a remake of the NeoGB Printer. The TinyGB Printer was ought to be our new common project but it did not because real life is what it is.
- [Toxa](https://github.com/untoxa) for refreshing my mind about some PNG format subtelties that greatly improved PNGenc integration into the project. He is also at the origin of the batteryless design.

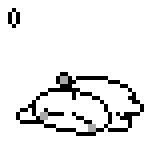
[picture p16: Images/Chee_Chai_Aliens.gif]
Chee Chai Aliens


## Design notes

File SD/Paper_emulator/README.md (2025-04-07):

## Some script to simulate thermal paper (requires a PC)

This is a [GNU Octave script](https://octave.org/) to simulate a thermal paper output. GNU Octave is a programming platform / langage for scientific computing, it can be used whatever your prefered OS.

Just drop some images in the **/Image_in** folder, run **Thermal_paper_emulator.m** script and enjoy your images freshly baked in **/Paper_out** folder. You can of course play with the [parameters](https://github.com/Raphael-Boichot/The-TinyGB-Printer/blob/11cf0198a5f711a38a46dcad767c037ce5f8676b/SD/Paper_emulator/Thermal_paper_emulator.m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) to modify paper hue and printing intensity.

You can also upload your images to the [GBCamera Android Manager](https://github.com/Mraulio/GBCamera-Android-Manager) and apply the exact same filter.

### Example of starting image
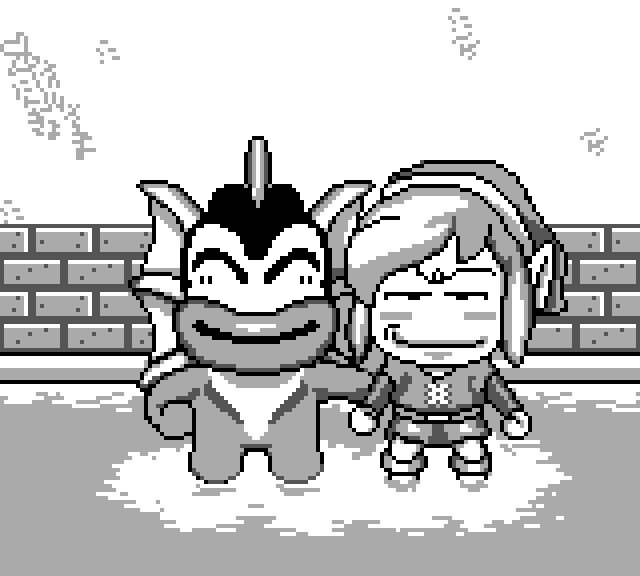
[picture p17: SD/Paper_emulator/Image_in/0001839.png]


### Example of simulated thermal paper (blue hue)


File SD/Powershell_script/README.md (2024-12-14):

## Some Powershell script

Script to be placed at the root of the SD card and ran to automatically set date / time of the system recursively (made whith ChatGPT). Just right-click then "Run with Powershell".

Do not hesitate to submit your own scripts !

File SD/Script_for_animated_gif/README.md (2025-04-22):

## Some script to create animated gif

This is a [GNU Octave script](https://octave.org/) to to create animated gif. GNU Octave is a programming platform / langage for scientific computing, it can be used whatever your prefered OS.

Just drop some images taken at different times in the /Pictures folder, run the code script and enjoy your animation !

You can also upload your images to the [GBCamera Android Manager](https://github.com/Mraulio/GBCamera-Android-Manager) and apply the exact same process.

## Example of animated gif
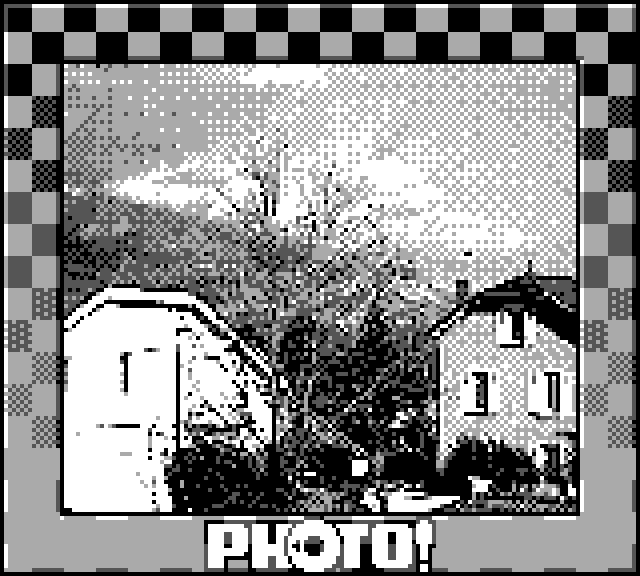
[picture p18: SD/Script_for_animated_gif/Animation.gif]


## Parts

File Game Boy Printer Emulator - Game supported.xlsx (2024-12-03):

Title | System | Supported | TX Rate | Compression | Palette | Printing mode advised | Comments
Creator: Raphaël BOICHOT
1942 (never released in Japan) | GBC | Yes | Normal | No | Custom | Margin | Palette 0x03 (2 colors) on purpose. You can print scores every 4 levels or at game over
Alice in Wonderland (never released in Japan) | GBC | Yes | Normal | No | Custom | Margin | Palette 0xD2 for the image, 0x47 for the footer. Eur version has no printing feature, only USA.
Animal Breeder 3 (あにまるぶりーだー3) | GB/GBC | Yes | Double | No | Standard | Margin | Palette 0xE4, average images to print
Animal Breeder 4 (あにまるぶり〜だ〜4) | GBC | Yes | Double | No | Standard | Margin | Palette 0xE4, very cute images to print
Aqualife (アクアライフ) | GB/GBC | Yes | Double | No | Standard | Margin | Palette 0xE4, you can print fish information from the tank menu, not from the encyclopedia
Asteroids (never released in Japan) | GB/GBC | Yes | Double | No | Standard | Margin | Palette 0xE4. One certificate at the end of game only (can be reached with cheat code). Enter "CHEATONX" as a password. Then while playing the game, press Select to display a cheat menu. Press Up or Down to select a level or Left or Right to select a zone. Press A for invincibility (001 will appear if done correctly).
Austin Power Episode 3 - Yeah Baby Yeah (unreleased rom CGBBA3P0.3) | GBC | Yes | Normal | No | Custom | Margin | Palette 0xE4 for "Shagulator", 0x1B text printing
Austin Power Episode 4 - Why Make Millions (unreleased rom CGBBA4P0.0) | GBC | Yes | Normal | No | Custom | Margin | Palette 0xE4 for "Frickulator", 0x1B text printing
Austin Powers: Oh, Behave! (never released in Japan) | GBC | Yes | Normal | No | Custom | Margin | Palette 0x1B, Poor printing content : shitty emails
Austin Powers: Welcome to My Underground Lair! (never released in Japan) | GBC | Yes | Normal | No | Custom | Margin | Palette 0x1B, Poor printing content : shitty emails
Cardcaptor Sakura: Itsumo Sakura-chan to Issho! (カードキャプターさくら 〜いつもさくらちゃんと一緒〜) | GB/GBC | Yes | Normal | No | Standard | Margin | Palette 0xE4, you can print custom banners.
Cardcaptor Sakura: Tomoe Shōgakkō Daiundōkai (カードキャプターさくら 〜友枝小学校大運動会〜) | GBC | Yes | Normal | No | Custom | Margin | Palette 0x1B, you can print custom banners.
Chee-Chai Alien (ちっちゃいエイリアン) | GBC | Yes | Normal | No | Standard | Margin | Palette 0xE4. You have to catch monster #10 (Kirako, キラコ) of the last "pheromone" list or level (about 3 hours required), play with it the minigame with printer connected and something weird happens...
Cross Hunter - Monster Hunter Version (クロスハンター モンスター・ハンター・バージョン) | GBC | Yes | Double | No | Custom | Margin | Palette 0x1B. To unlock print features, you have to access the professor laboratory (2-3 missions to complete) and discuss with him. It gives you access to all the bestiary to print.
Cross Hunter - Treasure Hunter (クロスハンター トレジャー・ハンター・バージョン) | GBC | Yes | Double | No | Custom | Margin | Palette 0x1B. To unlock print features, you have to access the professor laboratory (2-3 missions to complete) and discuss with him. It gives you access to all the bestiary to print.
Cross Hunter - X Hunter Version (クロスハンター エックス・ハンター・バージョン) | GBC | Yes | Double | No | Custom | Margin | Palette 0x1B. To unlock print features, you have to access the professor laboratory (2-3 missions to complete) and discuss with him. It gives you access to all the bestiary to print.
Daa! Daa! Daa! Totsuzen ★ Card de Battle de Uranai de!? (だぁ!だぁ!だぁ! とつぜん★カードでバトルで占いで!?) | GBC | Yes | Double | No | Standard | Margin | Palette 0xE4, you can print your character profile.
Daikaijuu Monogatari: The Miracle of the Zone II (大貝獣物語 ザ・ミラクル オブ ザ・ゾーンII) | GB/GBC | Yes | Normal | No | Standard | Margin | Palette 0xE4. Very complete printing features. You can print your card deck nearly from the beginning.
Dejiko no Mahjong Party (でじこの麻雀パーティー) | GBC | Yes | Normal | No | Standard | Margin | Palette 0xE4, I had to manipulate the wram with BGB to get infinite money to unlock things
Densha de GO! 2 (電車でGO!2) | GBC | Yes | Double | No | Standard | Margin | Palette 0xE4. You can print train images from the beginning
Dino Breeder 3 - Gaia Fukkatsu (ディノブリーダー3 〜ガイア復活〜) | GB/GBC | Yes | Double | Yes | Standard | Margin | Palette 0xE4. Uses a margin of 2 lines instead of 3 usually, you can print the ennemy that you have beaten in a kinf of death march but the game is horribly difficult and confusing.
Disney's Dinosaur (never released in Japan) | GBC | Yes | Normal | No | Standard | Margin | Palette 0xE4, you can print... dinosaurs unlocked by playing.
Disney's Tarzan (ディズニーズ ターザン) | GBC | Yes | Normal | No | Custom | Margin | Palette 0xE1, must be 0xD2 (LG and DG inverted)
Donkey Kong Country (ドンキーコング2001) | GBC | Yes | Normal | No | Standard | Margin | Palette 0xE4, you can print an alphabet and some images unlocked with level completed
Doraemon Kart 2 (ドラえもんカート2) | GB/GBC | Yes | Double | No | Standard | Margin | Palette 0xE4. Poor kart game. You can print the time records
Doraemon Memories - Nobita no Omoide Daibouken (ドラえもんメモリーズ のび太の想い出大冒険) | GB/GBC | Yes | Normal | No | Standard | Margin | Palette 0xE4. 44 images to unlock
Doraemon no Game Boy de Asobouyo Deluxe 10 (ドラえもんのGBであそぼうよ デラックス10) | GB | Yes | Normal | No | Standard | Margin | Palette 0xE4. You can print your scores at minigames.
Doraemon no Quiz Boy (ドラえもんのクイズボーイ) | GBC | Yes | Normal | No | Standard | Margin | Palette 0xE4. You have to beat the entire game to print a diploma. Honestly impossible to beat without emulator. No border at the end of image...
Dungeon Savior (ダンジョンセイバー) | GB/GBC | Yes | Normal | No | Standard | Margin | Palette 0xE4. You can print the characters of your team after their recruitment (it's a dungeon keeper game)
E.T.: Digital Companion (never released in Japan) | GBC | Yes | Normal | No | Standard | Timeout | Palette 0xE4. Lazy end of printing with blank packets rather than standard protocol (use of margins)
Fairy Kitty no Kaiun Jiten: Yousei no Kuni no Uranai Shugyou (フェアリーキティの開運辞典 妖精の国の占い修行) | GB/GBC | Yes | Normal | No | Standard | Margin | Palette 0xE4. Poor gameplay, you can print small stories.
Fisher-Price Rescue Heroes: Fire Frenzy (never released in Japan) | GBC | Yes | Normal | No | Standard | Margin | Palette 0xE4, you can print special badges by playing levels.
Game Boy Camera or Pocket Camera (ポケットカメラ) | GB | Yes | Normal | No | Standard | Margin | Palette 0xE4. One of the best game with the printer.
Golf Ou: The King of Golf (ゴルフ王) | GB/GBC | Yes | Double | Yes | Standard | Margin | Palette 0xE4. You can print your ranking, even if you loose. Leaked rom prototypes Golf Robot (rom DMGBGRE0.1) and Golf King (rom DMGBGRP0.2) have no printer support despite being the same game.
Hamster Club (ハムスター倶楽部) | GB/GBC | Yes | Double | No | Standard | Margin | Palette 0xE4. 88 different images to print, but boring as shit to unlock !
Hamster Paradise (ハムスターパラダイス) | GB/GBC | Yes | Normal | No | Standard | Margin | Palette 0xE4, lots of average hamster images to print. Custom borders.
Hamster Paradise 2 (ハムスターパラダイス2) | GBC | Yes | Double | No | Standard | Margin | Palette 0xE4, lots of average hamster images to print. Custom borders.
Harvest Moon 2 (牧場物語GB2) | GB/GBC | Yes | Normal | No | Custom | Margin | Palette 0xD2, you can prints events and insects from the book store in village.
Hello Kitty no Beads Koubou (ハローキティのビーズ工房) | GB/GBC | Yes | Normal | No | Standard | Margin | Palette 0xE4. You have to complete some puzzle rounds to allow printing something
Hello Kitty no Magical museum (ハローキティのマジカルミュージアム) | GB/GBC | Yes | Normal | No | Standard | Margin | Palette 0xE4. You can print about 45 cute images after completing puzzle games.
Hello Kitty Pocket Camera (ハローキティのポケットカメラ, unreleased rom GBDHKAJ0.2) | GB | Yes | Normal | No | Standard | Margin | Palette 0xE4, same as Game Boy Camera.
Jinsei Game Tomodachi takusan Tsukurou Yo! (人生ゲーム 友達たくさんつくろうよ!) | GB/GBC | Yes | Normal | No | Custom | Margin | Palette 0x00, you can print you character file from the main menu.
Kakurenbo Battle Monster Tactics (モンスタータクティクス) | GBC | Yes | Double | No | Standard | Margin | Palette 0xE4. You have to beat 2 bosses (easy) and discuss with people until an underground passage opens on top rigth of the map (just on top of your beginning room). The underground room with "M" in front of it contains the printer feature. Warning, the surface room with "M" in front is not the good one.
Kanji Boy (漢字BOY) | GB/GBC | Yes | Normal | No | Standard | Margin | Palette 0xE4. You can print your scores after a long quiz (second in the main menu) whatever the results
Karamuchou wa Oosawagi!: Okawari! (カラムー町は大さわぎ！おかわりっ！) | GB/GBC | Yes | Double | No | Standard | Margin | Palette 0xE4, you can print artworks from the main character.
Karamuchou wa Oosawagi!: Porinkiis to Okashina Nakamatachi (カラムー町は大さわぎ! 〜ポリンキーズとおかしな仲間たち〜) | GB/GBC | Yes | Double | No | Standard | Margin | Palette 0xE4, you can print artworks from the main character.
Kaseki Sousei Reborn II: Monster Digger (化石創世リボーン2 〜モンスターティガー〜) | GB/GBC | Yes | Double | No | Custom | Margin | Palette 0xE8, you can print your chimeras.
Kettou Transformers Beast Wars - Beast Senshi Saikyou Ketteisen (決闘トランスフォーマービーストウォーズ ビースト戦士最強決定戦) | GB/GBC | Yes | Normal | No | Custom | Margin | Palette 0x1B, you can print the special moves by pressing select in the adequate menu
Kidou Senkan Nadesico - Ruri Ruri Mahjong (機動戦艦ナデシコ ルリルリ麻雀) | GBC | Yes | Normal | No | Standard | Margin | Palette 0xE4, I had to manipulate the wram with BGB to unlock pictures
Kisekae Monogatari (きせかえ物語) | GB/GBC | Yes | Normal | No | Standard | Margin | Palette 0xE4. There is a kind of "paint" tool to play with the main character girl that you can access from beginning
Klax (never released in Japan) | GBC | Yes | Normal | No | Standard | Margin | Palette 0xE4. You can print password and an easter egg : The feature is accessed by selecting green alien, green alien, red circle, blue square. After skipping the found minigame page, a picture of a head attached to a body will display with an option to print. The heads can be selected with the D-Pad.
Konchuu Hakase 2 (昆虫博士2) | GB/GBC | Yes | Double | No | Standard | Margin | Palette 0xE4. You can print your insect catched. The net is given by an old man close to your house.
Little Nicky (never released in Japan) | GBC | Yes | Normal | No | Custom | Margin | Palette 0xC6. Poor printing options (one ugly custom image)
Logical (never released in Japan) | GBC | Yes | Normal | No | Standard | Margin | Palette 0xE4, the game is very hard to understand, you can print passwords (select pressed at the password screen).
Love Hina Pocket (ラブ ひな) | GBC | Yes | Double | No | Standard | Margin | Palette 0xE4. There is a TON of content to print (borders, stickers, sprites art). Printer emulator must be disconnected between prints, for unknown reasons.
Magical Drop (never released in Japan) | GBC | Yes | Normal | No | Standard | Margin | Palette 0xE4, you can print the high scores.
Mary-Kate and Ashley Pocket Planner (never released in Japan) | GB/GBC | Yes | Normal | No | Standard | Timeout | Palette 0xE4. Lazy end of printing with blank packets rather than standard protocol (use of margins)
McDonald's Monogatari : Honobono Tenchou Ikusei Game (マクドナルド物語) | GBC | Yes | Double | No | Custom | Timeout | Palette 0x30 (2 colors). You can print the result from the cashier minigame.
Mickey's Racing Adventure (never released in Japan) | GBC | Yes | Normal | No | Standard | Margin | Palette 0xE4, some nice artworks to unlock and print by winning courses. Margin = 0.
Mickey's Speedway USA (never released in Japan) | GBC | Yes | Normal | No | Standard | Margin | Palette 0xE4, some nice artworks to unlock and print by winning courses.
Mission: Impossible (never released in Japan) | GBC | Yes | Normal | No | Standard | Margin | Palette 0xE4, you can print your notes. Instead of margin, send a white packet with 0x00 as palette.
Monster ★ Race 2 (もんすたあ★レース2) | GB/GBC | Yes | Normal | No | Standard | Margin | Palette 0xE4. You have to unlock the passage to the south (forest) from the first village to get a kind of pokedex that serves as printing feature (after about one hour of gameplay)
Monster ★ Race Okawari (もんすたあ★レース おかわり) | GB | Yes | Normal | No | Standard | Margin | Palette 0xE4. You can rapidely print something after choosing your starter (after about 10 minutes of gameplay), from your individual menu
Nakayoshi Cooking Series 1 - Oishii Cake-ya-san (なかよしクッキングシリーズ1 おいしいケーキ屋さん) | GBC | Yes | Normal | No | Custom | Margin | Palette 0x07 (2 colors), you can print recipes.
Nakayoshi Cooking Series 2 - Oishii Panya-san (なかよしクッキングシリーズ2 おいしいパン屋さん) | GBC | Yes | Normal | No | Custom | Margin | Palette 0x07 (2 colors), you can print recipes.
Nakayoshi Cooking Series 3 - Tanoshii Obentou (なかよしクッキングシリーズ3 たのしいお弁当) | GBC | Yes | Normal | No | Custom | Timeout | Palette 0x1B, weird protocol but works, you can print recipes and food images.
Nakayoshi Cooking Series 4 - Tanoshii Dessert (なかよしクッキングシリーズ4 たのしいデザート) | GBC | Yes | Normal | No | Custom | Timeout | Palette 0x1B, weird protocol but works, you can print recipes and food images.
Nakayoshi Cooking Series 5 - Cake Wo Tsukurou (なかよしクッキングシリーズ5 こむぎちゃんのケーキをつくろう!) | GBC | Yes | Normal | No | Custom | Timeout | Palette 0x1B, weird protocol but works, you can print images of ingredients and characters when the game is completed at 100% only !
Nakayoshi Pet Series 1: Kawaii Hamster (なかよしペットシリーズ1 かわいいハムスター) | GB/GBC | Yes | Normal | No | Custom | Margin | Palette 0x1B, nice pixel art images to print are unlocked each time you do something new. 042-8DF-91A Game Genie code to unlock debug menu with printer features
Nakayoshi Pet Series 2: Kawaii Usagi (なかよしペットシリーズ2 かわいいウサギ) | GB/GBC | Yes | Normal | No | Custom | Margin | Palette 0x1B, nice pixel art images to print are unlocked each time you do something new. 042-8DF-91A Game Genie code to unlock debug menu with printer features
Nakayoshi Pet Series 3: Kawaii koinu (なかよしペットシリーズ3 かわいい仔犬) | GBC | Yes | Normal | No | Custom | Margin | Palette 0x1B, nice pixel art images to print are unlocked each time you do something new. 002-D2F-F7E Game Genie code to unlock debug menu with printer features
NFL Blitz (never released in Japan) | GB/GBC | Yes | Normal | No | Standard | Margin | Palette 0xE4, you can print your team statistics
Nintama Rantarou GB: Eawase Challenge Puzzle (忍たま乱太郎GB えあわせチャレンジパズル) | GB | Yes | Normal | No | Standard | Timeout | Palette 0xE4. You can unlock many cute "seals" by playing minigames or entering cheatcodes. Enter ZEEN then STOM in the code zone to unlock ton of seals and puzzles to print.
Ojarumaru: Mitsunegai Jinja no Ennichi de Ojaru! (おじゃる丸 〜満願神社は縁日でおじゃる!) | GB/GBC | Yes | Normal | No | Custom | Margin | Palette 0x1B, you have to mash the A button at the "Cold Sai and Ko-chan's fortune-telling" stand at the top center of the minimap to play and print the fortune messages.
Pachinko Data Card - Chou Ataru-kun (Pachinko Data Card ちょ〜あたる君) | GB | Yes | Normal | No | Custom | Margin | Palette 0x6C, protocol completely weird
Perfect Dark (never released in Japan) | GBC | Yes | Normal | No | Standard | Margin | Palette 0xE4. Each level completed unlock an image
Pocket Family 2 (ポケットファミリーGB2) | GBC | Yes | Normal | No | Custom | Margin | Palette 0x4C. Original cartridge mandatory, HuC-3 mapper. You can print family pictures with the game title.
Pocket Kanjirou (ポケット漢字郎) | GB | Yes | Normal | No | Standard | Margin | Palette 0xE4, you can print your scores
Pocket Puyo Puyo-n (ぽけっとぷよぷよ〜ん) | GBC | Yes | Normal | No | Standard | Margin | Palette 0xE4. No borders at the end of printings
Pokémon Card GB2: Great Rocket-Dan Sanjō! (ポケモンカードGB2 GR団参上!) | GB/GBC | Yes | Normal | Yes | Standard | Margin | Palette 0xE4, you can print your individual deck cards and the list of cards.
Pokémon Crystal (ポケットモンスター クリスタルバージョン) | GBC | Yes | Normal | No | Standard | Margin | Palette 0xE4, you can print images from Pokédex.
Pokémon Gold (ポケットモンスター 金) | GB/GBC | Yes | Normal | No | Standard | Margin | Palette 0xE4, you can print images from Pokédex.
Pokémon Picross (ポケモンピクロス, unreleased rom DMGAKVJ0.1) | GB/GBC | Yes | Normal | No | Custom | Margin | Palette 0x00, acts as 0xE4 (documented in pandocs). You can print the Pokédex.
Pokémon Pinball (ポケモンピンボール) | GB/GBC | Yes | Normal | No | Custom | Margin | Palette 0xE0 (3 colors), you can print the highscores only...
Pokémon Silver (ポケットモンスター 銀) | GB/GBC | Yes | Normal | No | Standard | Margin | Palette 0xE4, you can print your individual deck cards and the list of cards.
Pokémon Trading Card Game (ポケモンカードGB) | GB/GBC | Yes | Normal | Yes | Standard | Margin | Palette 0xE4, you can print your individual deck cards and the list of cards.
Pokémon Yellow: Special Pikachu Edition (ポケットモンスター ピカチュウ) | GB/GBC | Yes | Normal | No | Standard | Margin | Palette 0xE4, you can print images from Pokédex.
Pro Mahjong Tsuwamono GB (プロ麻雀兵 GB) | GB/GBC | Yes | Normal | No | Standard | Margin | Palette 0xE4, you can print statistics from the players. 0 margin protocol.
Purikura Pocket 3 - Talent Debut Daisakusen (プリクラポケット3 〜タレントデビュー大作戦〜) | GB | Yes | Normal | No | Custom | Margin | Palette 0xD2, the printer menu is hidden into the main in-game menu where you choose your day planning : press START to make it appear.
Puzzled (never released in Japan) | GBC | Yes | Normal | No | Standard | Margin | Palette 0xE4, you can print passwords
Quest for Camelot (never released in Japan) | GB/GBC | Yes | Normal | No | Standard | Margin | Palette 0xE4. Press Select on cartoon animations to print screen
Roadsters Trophy (never released in Japan) | GBC | Yes | Normal | No | Custom | Margin | Palette 0x27, you can print you password after a victory.
Sanrio Timenet: Kako Hen (サンリオタイムネット 過去編) | GB/GBC | Yes | Normal | No | Standard | Margin | Palette 0xE4. You can print from the Hello Kitty "Pokecenter" or from character menu
Sanrio Timenet: Mirai Hen (サンリオタイムネット 未来編) | GB/GBC | Yes | Normal | No | Standard | Margin | Palette 0xE4. You can print from the Hello Kitty "Pokecenter" or from character menu
Shinseiki Evangelion Mahjong Hokan Keikaku (新世紀エヴァンゲリオン 麻雀補完計画) | GBC | Yes | Normal | No | Standard | Margin | Palette 0xE4, I had to manipulate the wram with BGB to unlock pictures
SMARTCOM (never released in Japan) | GB | Yes | Normal | No | Standard | Margin | Palette 0xE4. Use Furrtek hack and restore the Nintendo logo to boot on real hardware
Sōko-ban Densetsu: Hikari to Yami no Kuni (倉庫番伝説 光と闇の国) | GB/GBC | Yes | Normal | No | Custom | Margin | Palette 0x00, you can print the little animation in options by pressing A during it.
Super Black Bass Pocket 3 (スーパーブラックバスポケット3) | GB/GBC | Yes | Double | No | Standard | Margin | Palette 0xE4. You can print your catches but fishing in this game is horribly frustrating.
Super Mario Bros. Deluxe (スーパーマリオブラザーズデラックス) | GBC | Yes | Double | No | Standard | Margin | Palette 0xE4. Very nice printing features to unlock by completing challenges
Sweet Angel (スウィートアンジェ) | GB/GBC | Yes | Normal | No | Standard | Margin | Palette 0xE4. You can print your profile and exchange it by serial cable
Sylvanian Families - Otogi no Kuni no Pendant (シルバニアファミリー 〜おとぎの国のペンダント) | GB/GBC | Yes | Double | No | Standard | Margin | Palette 0xE4. You can print the interior of your room (where you spawn initially) by pressing SELECT.
Sylvanian Families 2 - Irozuku Mori no Fantasy (シルバニアファミリー2～色づく森のファンタジー) | GBC | Yes | Normal | No | Standard | Margin | Palette 0xE4. You can print the interior of your room (where you spawn initially) by pressing SELECT.
Sylvanian Families 3 - Hoshi Furu Yoru no Sunadokei (シルバニアファミリー３ 星ふる夜のすなどけい) | GBC | Yes | Double | No | Standard | Margin | Palette 0xE4. You can print the flowerpots in your own menu (into the book) by pressing SELECT
Tales of Phantasia: Nakiri's Dungeon (テイルズ オブ ファンタジア なりきりダンジョン) | GB/GBC | Yes | Normal | Yes | Custom | Margin | Palette 0x00, acts as 0xE4 (documented in pandocs). You can print images of your team characters in diffrent costumes. Printing protocol spams 0F commands but works.
The Legend of Zelda: Link's Awakening DX (ゼルダの伝説 夢をみる島DX) | GB/GBC | Yes | Double | No | Standard | Margin | Palette 0xE4, You can print the photograph picture book.
The Little Mermaid 2: Pinball Frenzy (never released in Japan) | GBC | Yes | Normal | No | Custom | Margin | Palette 0x1B, you can print your scores and some images by playing minigames unlocked on tables.
Tony Hawk's Pro Skater 2 (never released in Japan) | GBC | Yes | Double | No | Custom | Margin | Palette 0x1B, some images to unlock by completing the levels. Password BT!!3T!!!!!! unlocks everything.
Trade & Battle: Card Hero (トレード&バトル カードヒーロー) | GB/GBC | Yes | Normal | No | Custom | Margin | Palette 0x2D, LG and DG inverted on sprites. If palette 0x1E is forced, sprites are OK but text unreadable
Tsuri Sensei 2 (釣り先生2) | GB/GBC | Yes | Normal | No | Standard | Margin | Palette 0xE4, you can print your catches.
VS Lemmings (VS.レミングス) | GBC | Yes | Double | No | Standard | Margin | Palette 0xE4. Lemmings (USA) has no printer support but it is the same game without VS mode (it is a downgraded version from VS Lemmings).

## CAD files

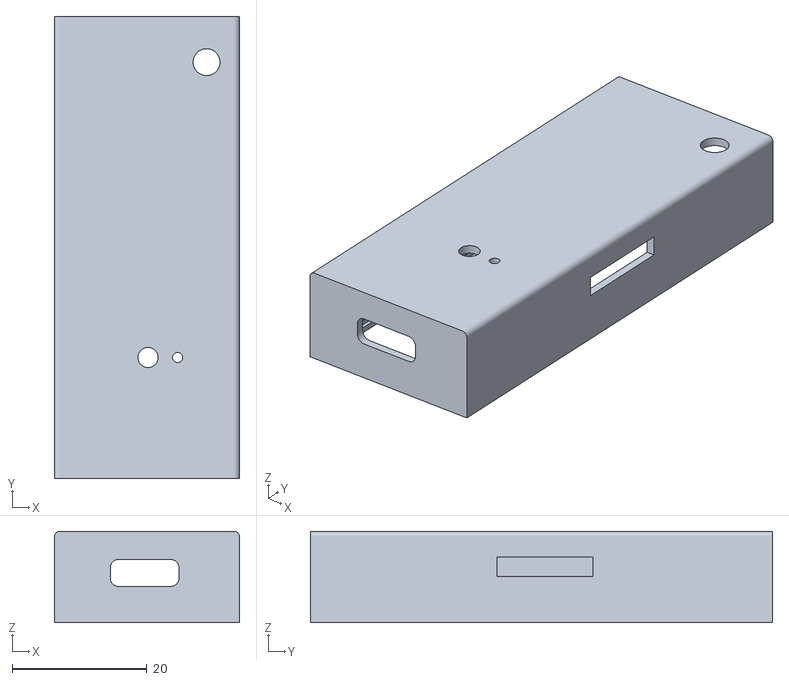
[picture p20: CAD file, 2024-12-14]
PCB_1.0_without_TFT/3D_printed_enclosure/Enclosure.stl
27.5 x 68.7 x 13.6

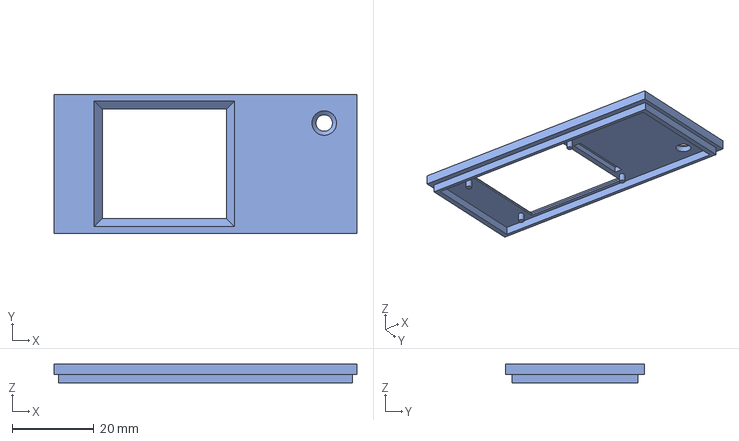
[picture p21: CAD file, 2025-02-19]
PCB_2.0_with_TFT/3D_printed_enclosure/GBPrinter - Lid.step
74.0 x 34.0 x 4.60 mm

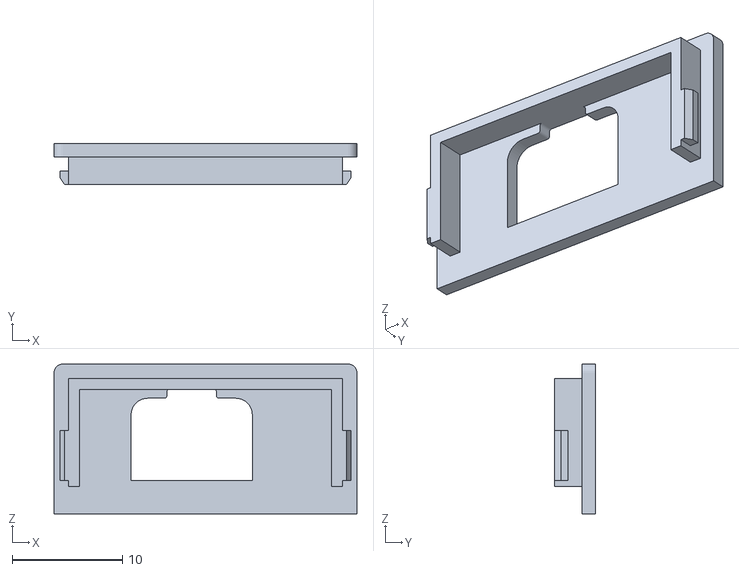
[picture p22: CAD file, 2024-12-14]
PCB_1.0_without_TFT/3D_printed_enclosure/Enclosure Endcap.stl
27.5 x 3.70 x 13.6

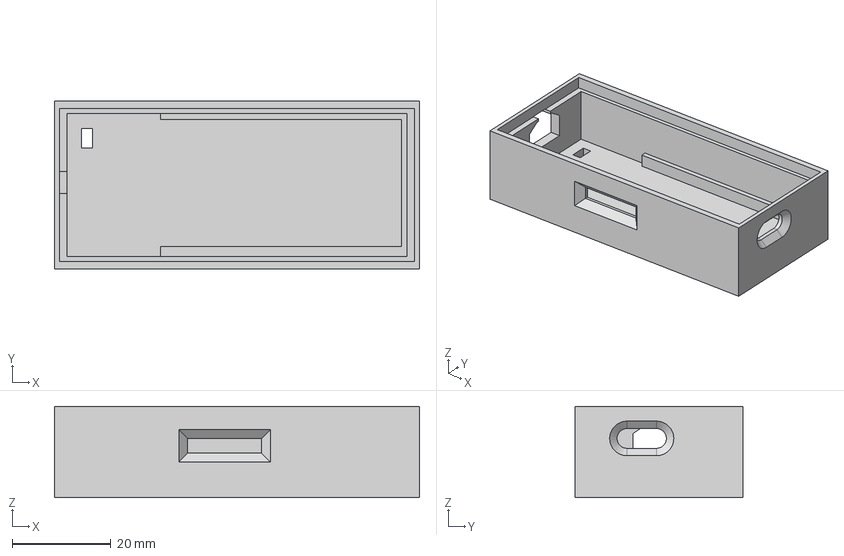
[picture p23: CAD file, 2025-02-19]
PCB_2.0_with_TFT/3D_printed_enclosure/GBPrinter - Base.step
74.0 x 34.0 x 18.5 mm

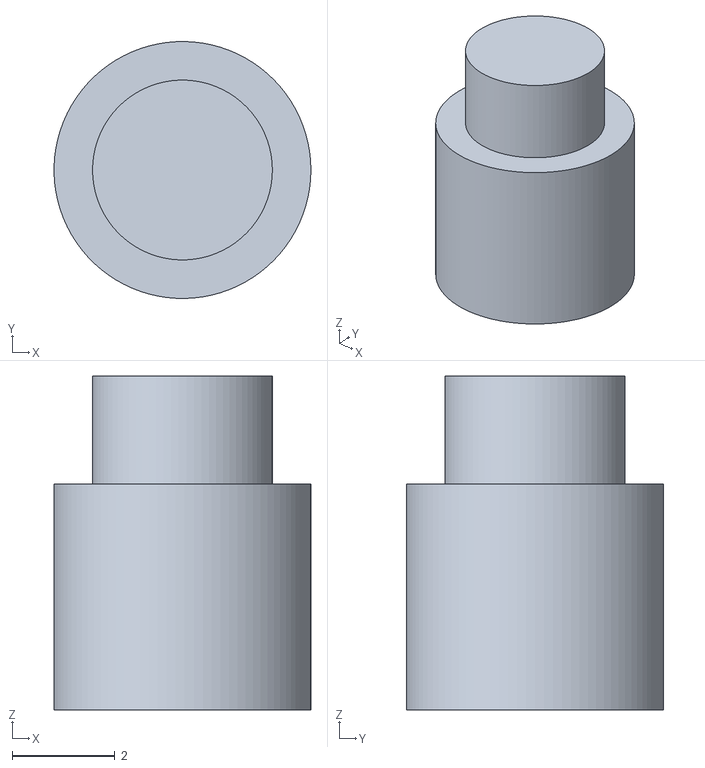
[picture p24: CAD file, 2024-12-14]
PCB_1.0_without_TFT/3D_printed_enclosure/Button.stl
5.00 x 5.00 x 6.50

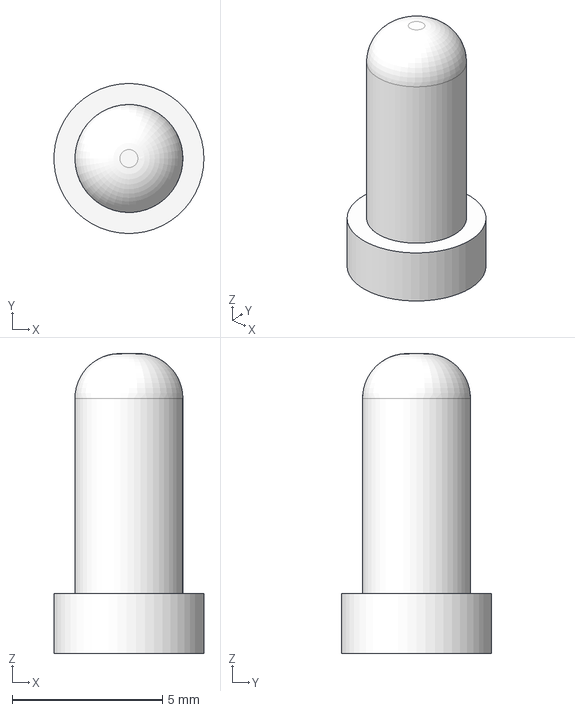
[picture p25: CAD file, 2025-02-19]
PCB_2.0_with_TFT/3D_printed_enclosure/GBPrinter - Button.step
5.00 x 5.00 x 10.0 mm

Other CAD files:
PCB_2.0_with_TFT/3D_printed_enclosure/GBPrinter - Base.stl
PCB_2.0_with_TFT/3D_printed_enclosure/GBPrinter - Button.stl

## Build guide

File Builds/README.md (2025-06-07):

Connect your Pico to the PC while pressing BOOT and drop the uf2 file into the folder that appears. That's all !
- the "one folder per boot" is the regular version (1024 files per folder, one folder per boot)
- the "100 files per folder" mimics the folder numbering of the BitBoy (folder number does not increment at boot)
- The "pico-gb-printer" version allows you to play with [this project](https://github.com/untoxa/pico-gb-printer). Connect the board to a PC and get your images directly from the [dedicated web interface](http://192.168.7.1/).

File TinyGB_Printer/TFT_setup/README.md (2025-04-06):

## How to configure the Bodmer TFT library

- Locate the TFT_eSPI library: **\Arduino\libraries\TFT_eSPI** folder in your Arduino libraries
- copy the configuration file (TinyGB_240x240.h) for the TFT display in this folder.
- edit the User_Setup_Select.h and modify line 29:

    **#include <TinyGB_240x240.h> // Default setup is root library folder**
  
- edit the TFT_eSPI_RP2040.h and modify line 52

   **#define SET_BUS_READ_MODE  // spi_set_format(SPI_X,  8, (spi_cpol_t)0, (spi_cpha_t)0, SPI_MSB_FIRST)**

This correspond to this issue with this particular TFT display: [https://github.com/Bodmer/TFT_eSPI/issues/3476](https://github.com/Bodmer/TFT_eSPI/issues/3476)

Now you're ready to compile !

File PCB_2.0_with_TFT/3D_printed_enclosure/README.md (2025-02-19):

## 3D printed enclosure by [Slade1972](https://github.com/Slade1972)

The building instructions can be found on [Printables](https://www.printables.com/model/1196769-the-tinygb-printer-case). The licence for the 3D case is [CC BY-NC-SA 4.0](https://creativecommons.org/licenses/by-nc-sa/4.0/).


(image credit: [Slade1972](https://github.com/Slade1972))

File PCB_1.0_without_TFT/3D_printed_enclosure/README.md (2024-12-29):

## 3D printed enclosure by [Björn Heirman](https://github.com/BjornB2)

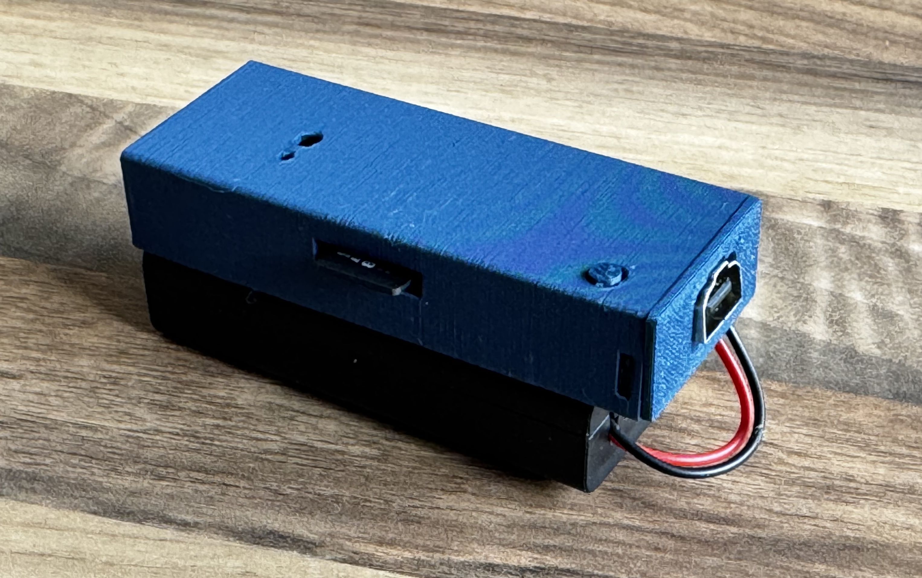
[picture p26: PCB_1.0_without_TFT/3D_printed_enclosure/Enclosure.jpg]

(image credit: Björn Heirman)

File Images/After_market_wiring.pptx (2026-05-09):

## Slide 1

After market cables wiring

VCC

VCC

SD

SD

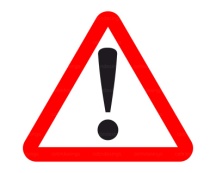
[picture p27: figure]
Peut inclure: Un panneau de signalisation triangulaire rouge avec un point d'exclamation noir au centre.

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
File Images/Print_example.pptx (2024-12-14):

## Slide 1

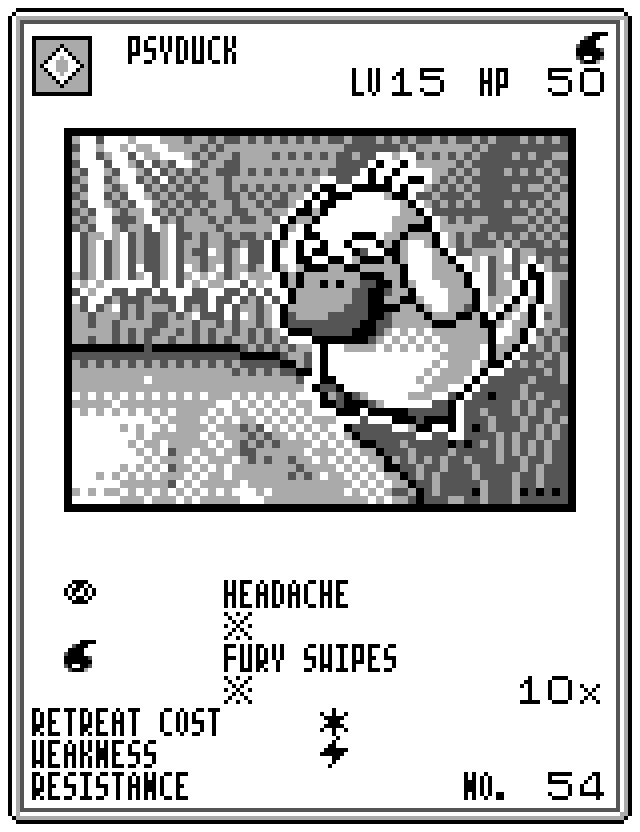
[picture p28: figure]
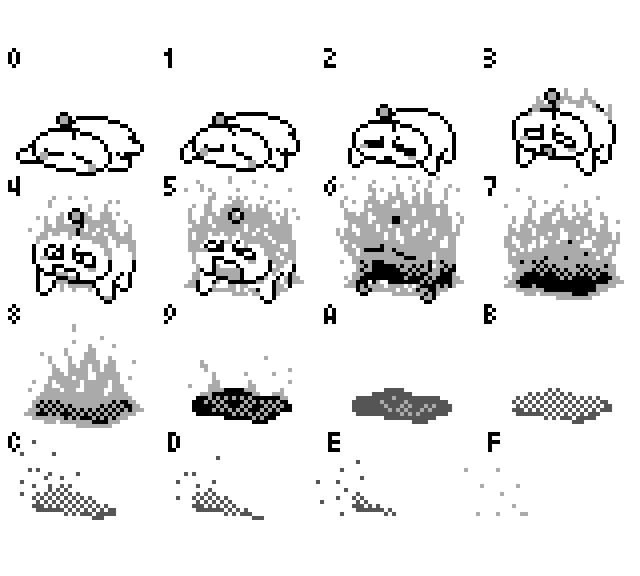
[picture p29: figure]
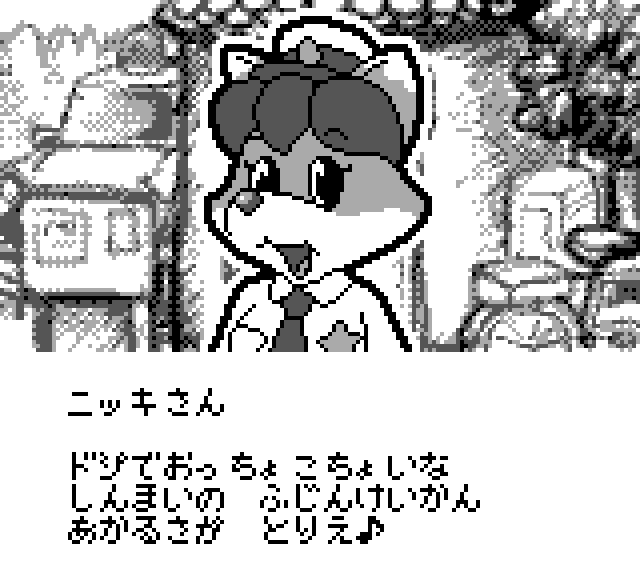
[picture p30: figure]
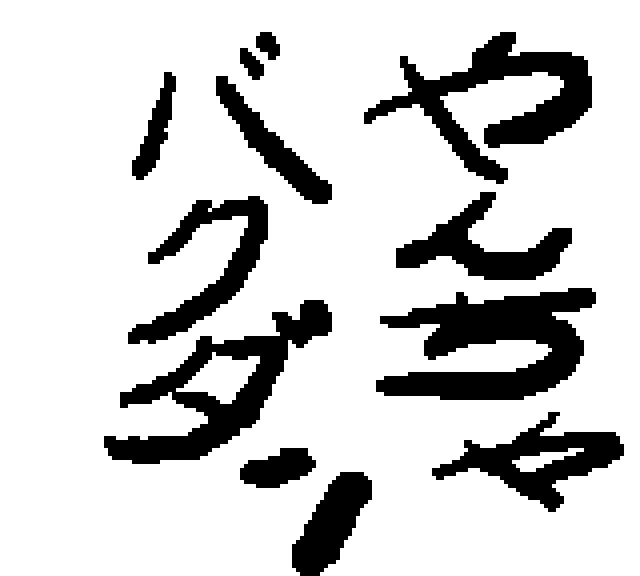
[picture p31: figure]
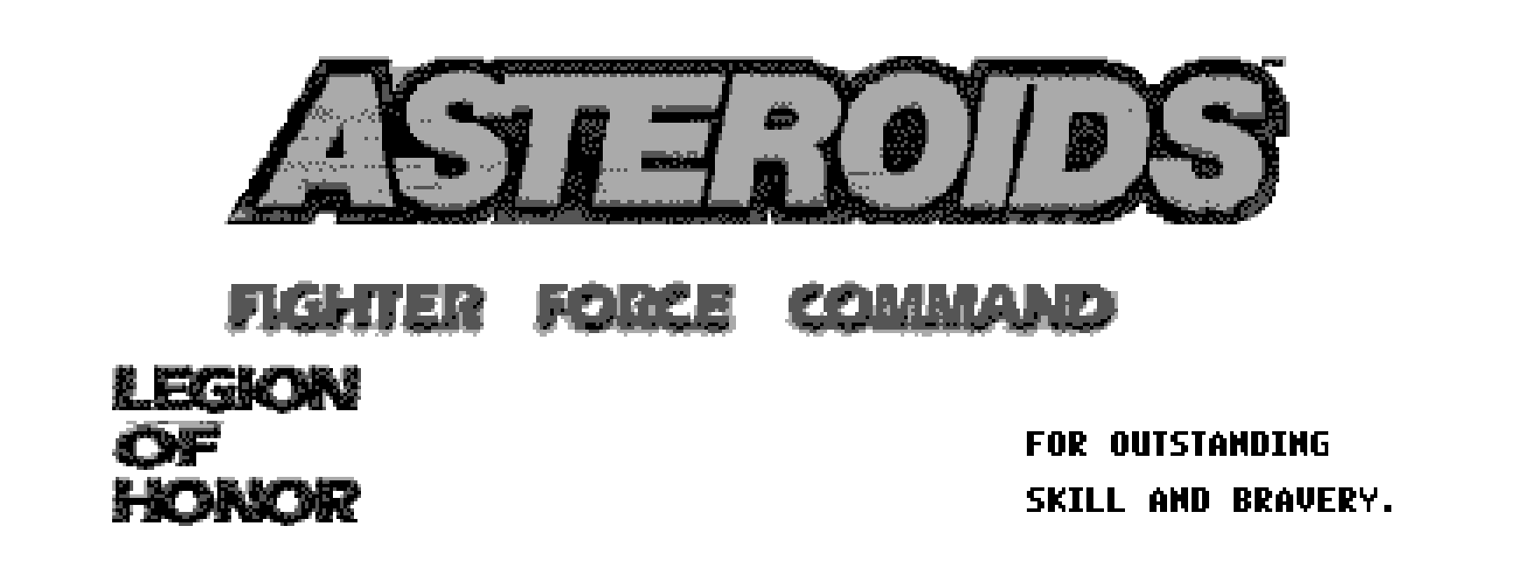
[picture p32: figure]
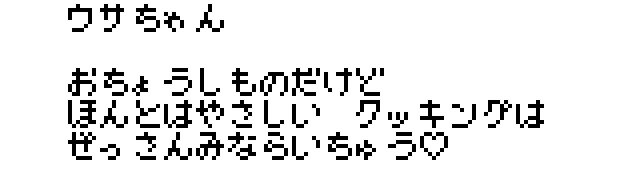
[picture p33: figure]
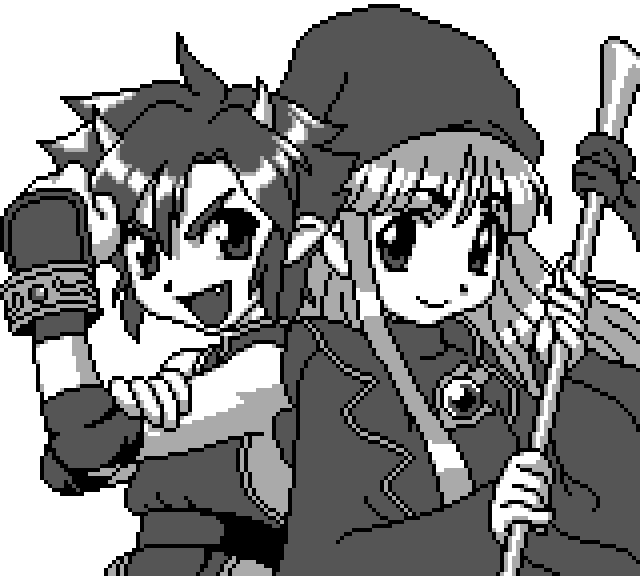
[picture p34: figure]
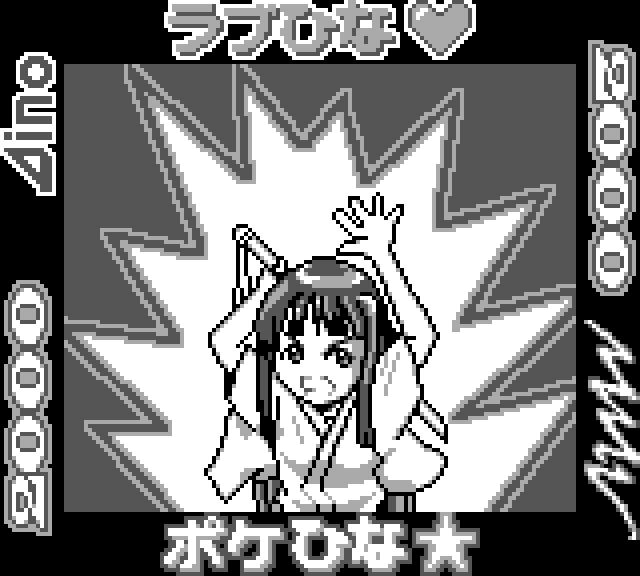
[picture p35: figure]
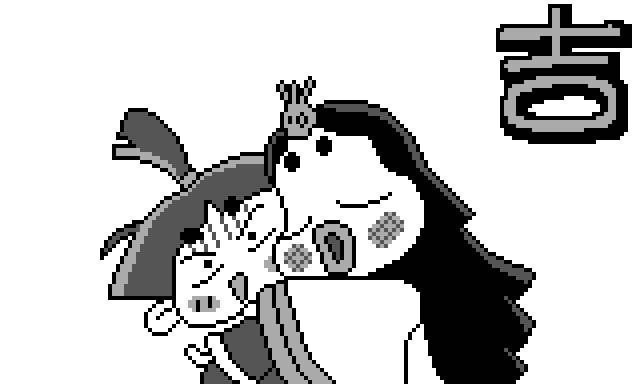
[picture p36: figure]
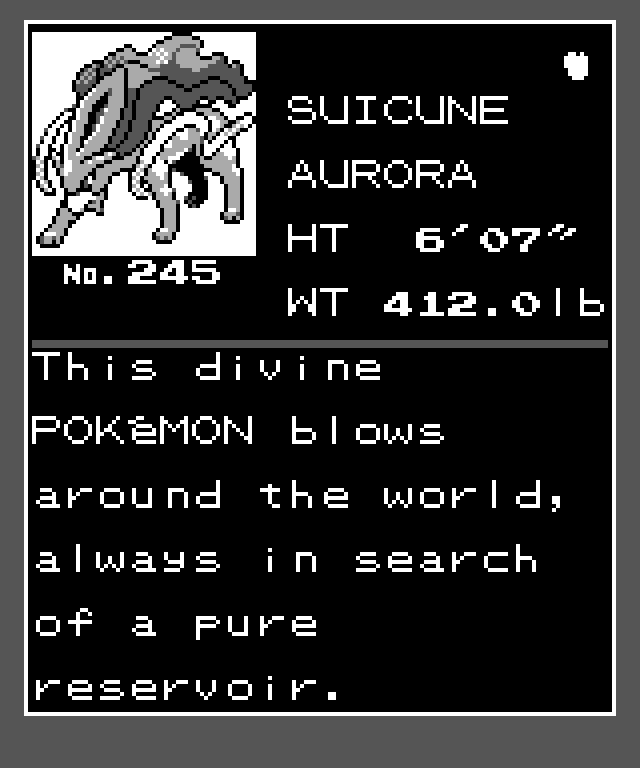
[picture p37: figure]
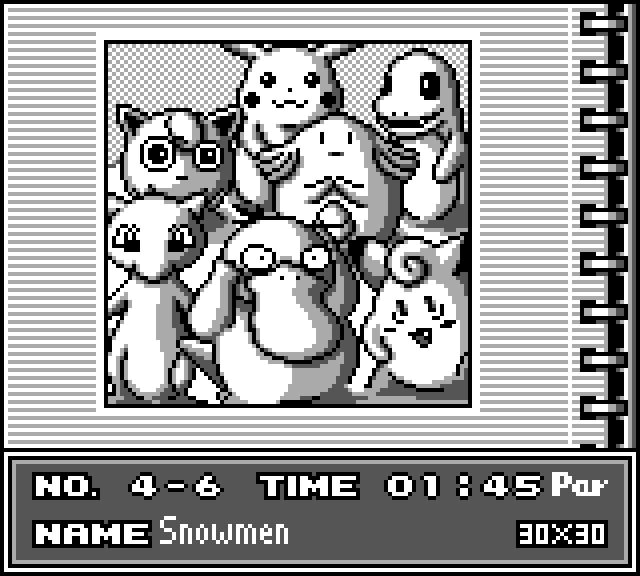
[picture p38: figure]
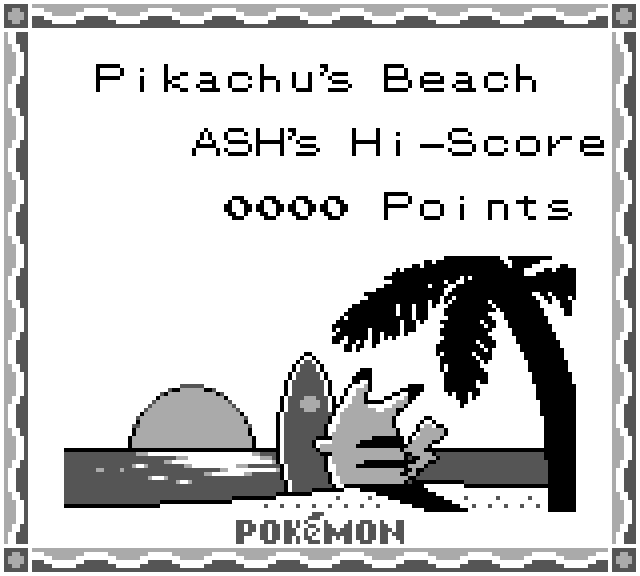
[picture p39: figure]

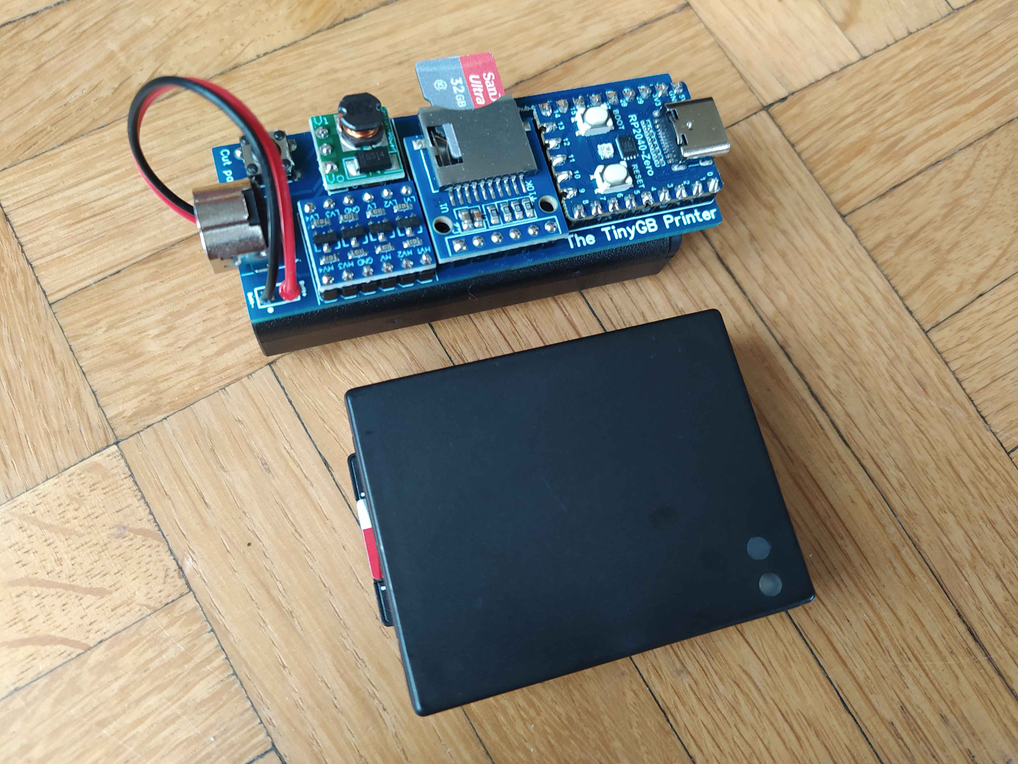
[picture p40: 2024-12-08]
Images/TinyGB_Printer_vs_bitboy.jpg

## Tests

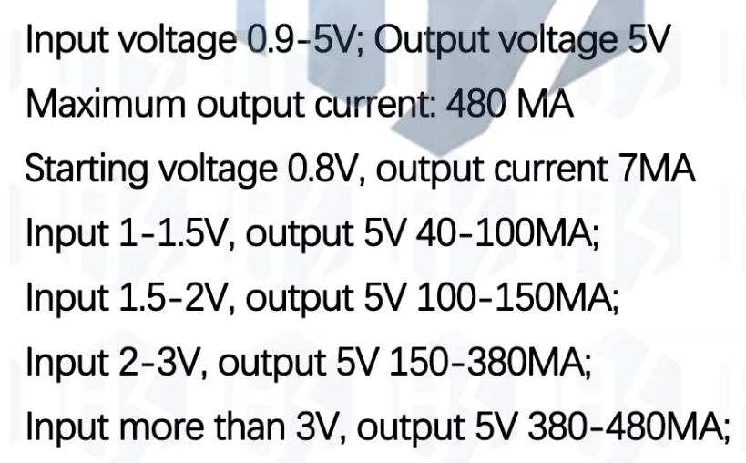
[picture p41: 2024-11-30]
Images/DC_DC_characteristics.png

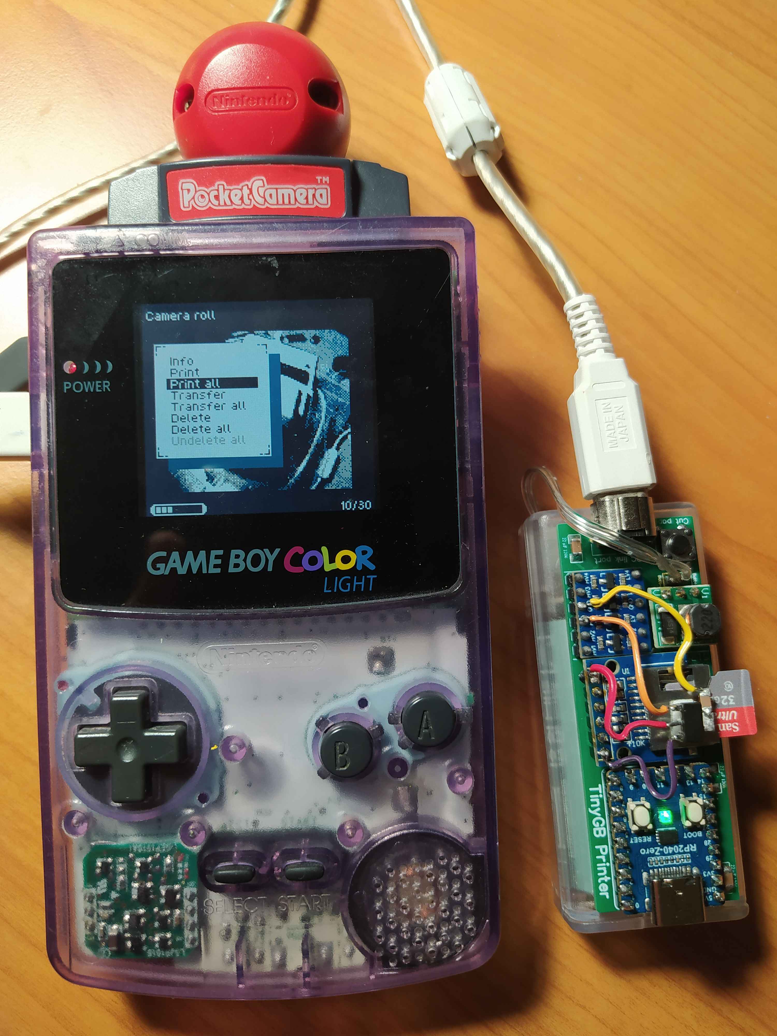
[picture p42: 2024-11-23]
Images/Stress_test_with_prototype_2.jpg

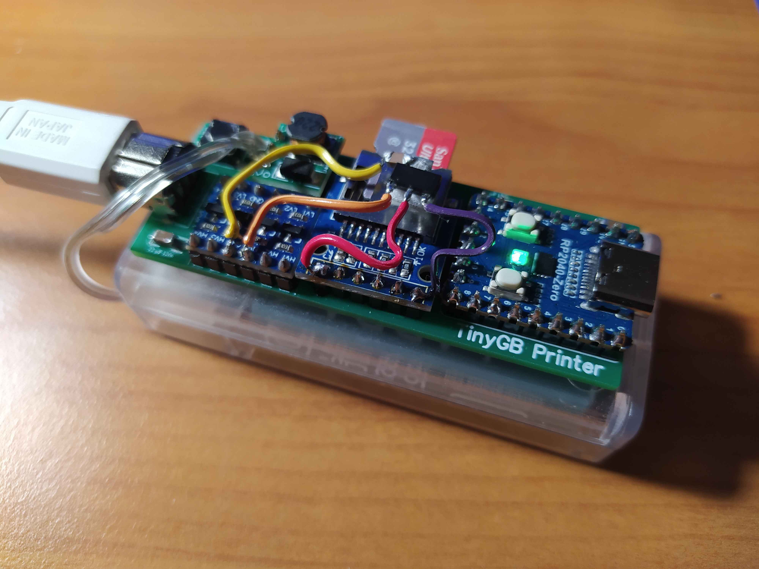
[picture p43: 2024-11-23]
Images/Stress_test_with_prototype_1.jpg

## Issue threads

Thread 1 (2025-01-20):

Non French AliExpress Links and fake levels shifters

Slade1972, 2025-01-20:
Hey, this project is awesome. And it's going onto my "things to do really soon" list.  My only frustration is that you've provided French specific AliExpress links, which is a bit of a pain, as AliExpress has a habit of forcing all future site visits to be in the previously selected link format. In this case, it changes the site to be in French, and becomes a challenge to change it back to English.

So, here are some of the same and some alternative links to the same items. They are all standard www and .com links. Any changes were made due to the seller not sending the item to Australia or the item having been found cheaper from another vendor with the "Choice" option.

[Micro SD Module](https://www.aliexpress.com/item/1005005302035188.html) - Pick the 'No Welding' option if you want, it'll save a few cents, and since you're soldering everything yourself anyway, why not?

[1.3 inch TFT Display](https://www.aliexpress.com/item/1005007143117779.html) - Don't grab the smaller one.
[
4 Channel Logic Level Converter](https://www.aliexpress.com/item/1005006255186878.html) - Make sure to grab the 4 channel, not the 2 channel. Sadly the minimum order / amount you get is 5, but it's still cheap. Buying 10 only costs a small amount more and gives you lots of spares.

[5v DC to DC converter](https://www.aliexpress.com/item/32809095271.html) - Same seller as the original link. Make sure to grab the 5v version. I could not find a blue PCB version in the "Choice" range. The other one linked had expensive shipping at around $8 AUD.

[Male and Female headers](https://www.aliexpress.com/item/4000873858801.html) - 10 male and 10 female header sets. 40 pins each. This should be more than enough.

[Gameboy (etc) External Link Port](https://www.aliexpress.com/item/1005006358075502.html) - This one is currently (20th Jan 2025) discounted to under $2 AUD. The [original link](https://www.aliexpress.com/item/1005006361884480.html)  is about the same price, but won't ship to Australia. **Edit: This port is for the Gameboy Advance, and it's backwards compatible (with the right cable) with the Gameboy Pocket and Colour. The port is different to the original Gameboy.**

[Push Buttons](https://www.aliexpress.com/item/1005003938244847.html) - Same as the original link. Make sure you get the 4 pin with the short legs, not the 2 pin.

[22 µf caps with 1206 footprint](https://www.aliexpress.com/item/1005006022131059.html) - (22 to 50 µF is OK if you have spares). Take 10V or 16V. Same as original link. These come in packs of 20, you only need to buy a quantity of 1, unless you're making more than 10 of these devices.

[AMS1117-3.3v converter](https://www.aliexpress.com/item/4001104149446.html) - Same link. Grab the 3.3v not the ADJ. There's 20 of them... Lots of spares, I guess.

[Triple A Battery Holder (2xAAA)](https://www.aliexpress.com/item/1005004195965365.html) - Get the one with leads, not the plug. Same as the original link.

[Double A Battery Holders](https://www.aliexpress.com/item/1005005489778785.html) - These are smaller profiles and there's a variety to choose from if you want a smaller package. No on/off switch on these though.
[
Double A Battery Holder](https://www.aliexpress.com/item/4001270779608.html) - These have a case / switch.

I hope this doesn't come across as mean or rude. It's not meant to be. I'm just trying to help other people work past the AliExpress flaws. I got "burnt" on a Russian link a few months back and had to clear my cache and cookies just to get the site back to English. Changing the settings on AliExpress alone didn't help, every link no matter what would end up at the Russian AliExpress site.

Raphael-Boichot, 2025-01-20:
Hello Slade.

I will update the links and take into account your modifications. Thanks for the feedback.

Raphaël

Raphael-Boichot, 2025-01-20:
Just to mention it, the SD module pins must be soldered backward compared to pre-soldered units, so it must **not** be pre-soldered.

Slade1972, 2025-01-20:
> Just to mention it, the SD module pins must be soldered backward compared to pre-soldered units, so it must **not** be pre-soldered.

Thanks for letting me know. I didn't notice. I'm just cheap :) A few cents in my pocket, is a few cents I can spent elsewhere. I've ordered the parts, and now have to order the boards and wait for those to arrive. Hopefully in a few weeks time I'll have a working Gameboy "printer".

You might want to add the right Gameboy link cable too. Here's [one](https://www.aliexpress.com/item/1005006479007710.html) option (get the 'for GBC') that will work on a Gameboy Color (I never understood why it uses American spelling) and Gameboy Pocket. Here's [another](https://www.aliexpress.com/item/1005006818879722.html) that is slightly dearer. Same thing, get the GBC version if you have a Gameboy Pocket or Color.

Reading through Wikipedia it seems as though the 3rd gen GBA link cables are not backwards compatible with the Gameboy Pocket and Color, so buying the wrong cable (that would suit the socket) wouldn't plug into the GBP or GBC.

Raphael-Boichot, 2025-01-20:
Yes, good idea, I'm adding a link to a GBC cable. And I confirm, the purple GBA cable has different pinout, so not compatible.

Slade1972, 2025-01-20:
Thanks again. I've ordered the PCB's and picked standard shipping, so it'll take a few weeks for them to arrive. I will admit to being very surprised that it cost less than $5 AUD including shipping after JLCPCB added some small discount to the cost.

Hopefully by mid February I should have a working unit.

For anyone else, when ordering from JLCPCB just remember to change the default shipping. Mine was set to DHL and would have cost $28 AUD, which is great if you want the boards within a few days, but not if you're trying to save a bit of money and don't mind waiting.

Raphael-Boichot, 2025-01-21:
JLPCB cannot be beaten if you take the standard shipping. Plus quality is top. This why I recommend only this supplier at the moment.

Slade1972, 2025-01-28:
A quick update: I'm still waiting for parts to arrive, with both AliExpress orders and the JLPCB order having made it to Australia. Nothing moves quickly when it hits Australian shores, however. Mail can often take a week to go from Sydney airport and move the 35kms to my house.  And then there's this possible issue:

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

Given that the AliExpress order contains no other items than what is on the BOM, I'm not sure what item(s) would be restricted.  I'm just going to hope that what ever is missing I can get locally at a reasonable price (or at all).

Raphael-Boichot, 2025-01-29:
Curious to see what "restricted items" the project uses 😁

Slade1972, 2025-01-29:
Yeah, that's possible. After Samsung decided they'd try to burn everything down with dud batteries, a lot of countries panicked and put lithium batteries on a no fly list. I suppose the word battery might have triggered something.  Here's hoping they just open the package, realise what's in there and send it on it's way. I know I can get battery boxes locally, albeit at an elevated price.

Worst case scenario I get none of the package at all...  That will be frustrating and expensive.

On the plus side, the PCB's have moved to a local courier / delivery company. They should turn up within the next day or two.
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
Raphael-Boichot, 2025-02-12:
My pleasure, I like solving problems.

Slade1972, 2025-02-13:
> As these were made with a pick and place machine used for industrial production, there is probably millions of them flooding the market now... Sellers are maybe even not aware of that.

And there in lies the problem of even buying from Amazon. The pictures are almost always "stolen" from some other vendor and don't always reflect what the vendor is selling.  AliExpress is far worse, with stolen images from other shops with the other shop logo plastered across it.  There really is no way of telling whether you're going to get exactly what the picture shows.

> But I saw your comment on Aliexpress ;-)

All I can do it try to warn other people. Sadly, I had no way of knowing that the LS didn't work at the time.

It took a bit of time to do, because, my goodness those **parts are small**, but eventually I managed to swap them around.  Sure it's not the best soldering, but they're in the right place.

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

First boot, nothing. Not even screen came on.  I went back and touched up a few points, tried to move the resistors a bit more, push the transistors (??) down against the pads, make sure I hadn't shorted anything. Then it booted, yay. It still didn't work and I got nothing but a printer error on the Gameboy, but it booted.

Repeat the above process, check voltages, etc. Tried powering it from USB and all I get is a bright green LED on the RP2040. That's something different. Back to batteries, screen comes alive and no SD card inserted error. Whoops.

I fixed that, and tried again to print and.....

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

That's my rainwater tank and air conditioner unit.  Colour me impressed, it works !

Having said that, I think I'll just buy the level shifters from Amazon, it took around an hour to move all the components around with a soldering iron. A hot air rework station or soldering pad (the small ones that heat up) would work wonders, but I have neither for the moment and I'm not sure either is worth buying to fix a $1 component.

Raphael-Boichot, 2025-02-13:
Nice ! I'm happy to see it work !

If you fall into Game Boy Camera photography, there is a Telegram chatroom you could join : https://t.me/gameboycamera

It's a peacefull server with some big guns of the camera/printer modding community.

Slade1972, 2025-02-14:
> Nice ! I'm happy to see it working !

Thanks. I am surprised at just how rubbish the images are, but I do have to remember how old this is, and how cheap it would have been at the time.

> If you fall into Game Boy Camera photography, there is a Telegram chatroom you could join : https://t.me/gameboycamera
>
> It's a peaceful server with some big guns of the camera/printer modding community.

I'm going to have to put on a hard hat and safety glasses and change my name to Alice if I climb down that rabbit hole. I'm such a sucker for old and quirky handhelds / tech. I have a [Playdate](https://play.date/) coming as a belated birthday present.

I would like to find another (preferably broken) Gameboy camera to extract the main rom from to make one of those mini cameras. I will admit to not liking the idea of breaking open a working camera "just because". It seems such a waste of legacy tech that isn't being made anymore.  The downside is the cost, Gameboy cameras have been rising in price in Australia and they're often sold for upwards of $150AUD or 90 Euros, with an average price of around $100AUD.

Hopefully I'll see you on the telegram chat :)

Raphael-Boichot, 2025-02-14:
Seing the local price it's worth considering buying a batch at J4U or some other Japanese shops. In Europe they are now at about 25€, which is not the pre COVID price but yet reasonable for tinkering some.

Slade1972, 2025-02-16:
> Seing the local price it's worth considering buying a batch at J4U or some other Japanese shops. In Europe they are now at about 25€, which is not the pre COVID price but yet reasonable for tinkering some.

Oh man, that site is dangerous. So many handhelds I don't own !! Both a Wonderswan and Wonderswan Colour are on there, as well as actual Gameboy printers and cameras and the "mythical" (never released in Australia) Gameboy Light.

I'm going to need to sell a kidney.  Sadly, I did not see any bulk Gameboy cameras there. Most of the prices were around $50USD, which, at the moment, is in the ballpark of $75AUD, plus shipping.  It doesn't make them very cheap.

Raphael-Boichot, 2025-02-19:
I consider this issue as closed, thanks a lot for your feedback !
Let's continue on the discussion section

Closed 2025-02-19.

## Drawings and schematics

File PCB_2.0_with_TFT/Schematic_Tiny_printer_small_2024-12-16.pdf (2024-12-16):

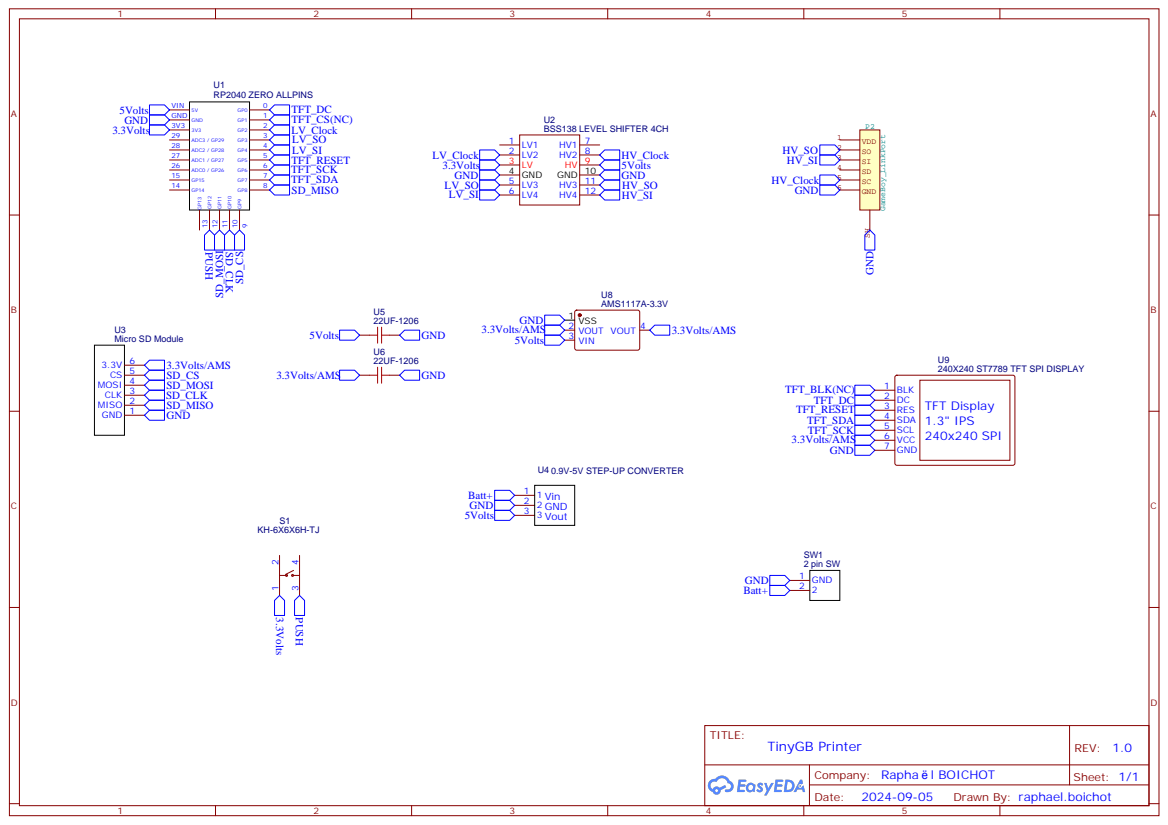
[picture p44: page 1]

Drawn By: raphael.boichot

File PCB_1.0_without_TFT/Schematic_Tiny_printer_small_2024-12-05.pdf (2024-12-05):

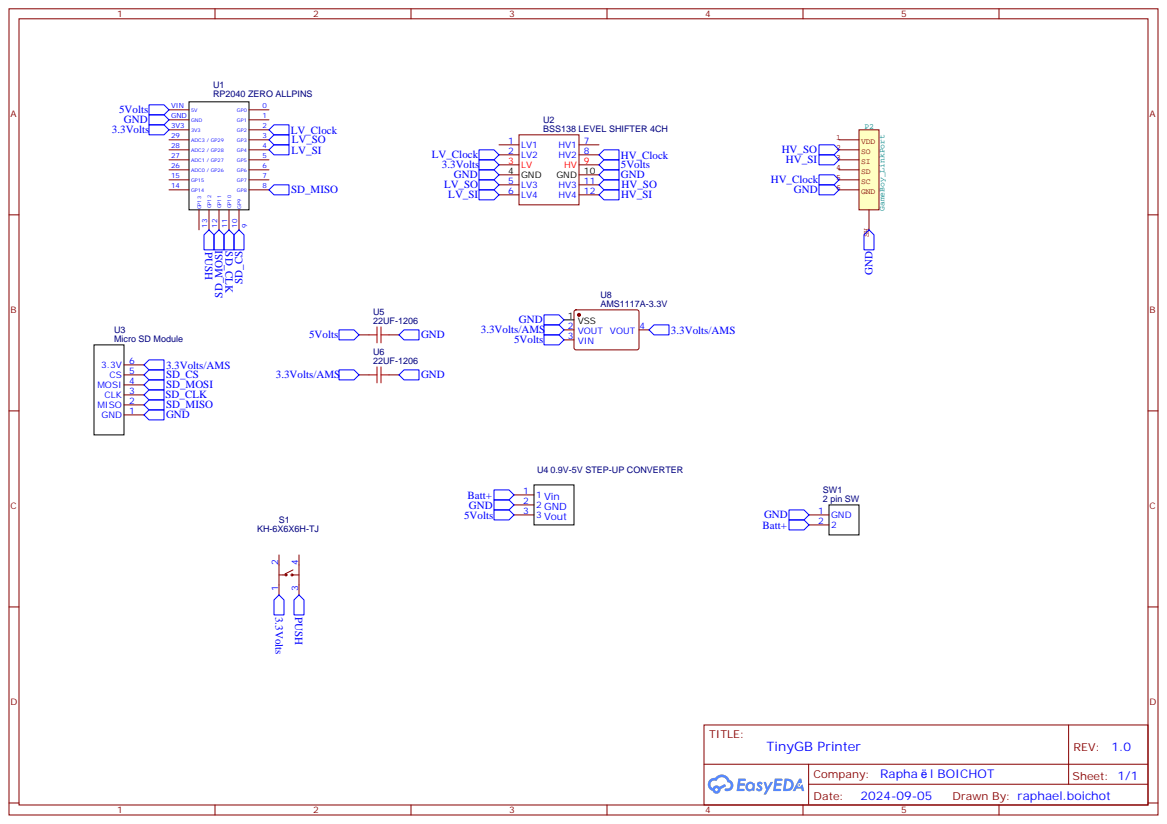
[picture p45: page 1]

Drawn By: raphael.boichot

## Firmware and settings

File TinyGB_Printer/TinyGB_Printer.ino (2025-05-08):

/*************************************************************************
 *
 * GAMEBOY PRINTER EMULATION PROJECT V3.2.1 (Arduino)
 * Copyright (C) 2022 Brian Khuu
 *
 * PURPOSE: To capture gameboy printer images without a gameboy printer
 *          via the arduino platform. (Tested on the arduino nano)
 *          This version is to investigate gameboy behaviour.
 *          This was originally started on 2017-4-6 but updated on 2020-08-16
 * LICENCE:
 *   This file is part of Arduino Gameboy Printer Emulator.
 *
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
 */

#include <stdint.h>
#include <stddef.h>
#include "gameboy_printer_protocol.h"
#include "gbp_serial_io.h"

/////////////Specific to TinyGB Printer//////////////
#include <hardware/gpio.h>
#include <Adafruit_NeoPixel.h>
#include <SPI.h>  //for SD
#include <SD.h>   //for SD
#include "Upscalerlib.h"
#include "config.h"
#include "splash.h"
#include <TFT_eSPI.h>  // Hardware-specific library
#include <SPI.h>
TFT_eSPI tft = TFT_eSPI();            // Invoke custom library
TFT_eSprite img = TFT_eSprite(&tft);  // Create Sprite object "img" with pointer to "tft" object
                                      // the pointer is used by pushSprite() to push it onto the TFT
//Please read this topic: https://github.com/Bodmer/TFT_eSPI/issues/3476
//in TFT_eSPI_RP2040.h, you have to comment a command to allow this particular 240x240 display to work :
//#define SET_BUS_READ_MODE  spi_set_format(SPI_X,  8, (spi_cpol_t)0, (spi_cpha_t)0, SPI_MSB_FIRST)
//must be replaced by:
//#define SET_BUS_READ_MODE  // spi_set_format(SPI_X,  8, (spi_cpol_t)0, (spi_cpha_t)0, SPI_MSB_FIRST)
//It's a trap for who never reads the code comments ^^
/////////////Specific to TinyGB Printer//////////////

#define GBP_BUFFER_SIZE 650  //maximal size of data buffer 640 bytes + commands
#define GBP_FEATURE_PARSE_PACKET_MODE
#define GBP_FEATURE_PARSE_PACKET_USE_DECOMPRESSOR
#include "gbp_pkt.h"

/*******************************************************************************
*******************************************************************************/
/* Serial IO */
// This circular buffer contains a stream of raw packets from the gameboy
uint8_t gbp_serialIO_raw_buffer[GBP_BUFFER_SIZE] = { 0 };

#ifdef GBP_FEATURE_PARSE_PACKET_MODE
/* Packet Buffer */
gbp_pkt_t gbp_pktState = { GBP_REC_NONE, 0 };
uint8_t gbp_pktbuff[GBP_PKT_PAYLOAD_BUFF_SIZE_IN_BYTE] = { 0 };
uint8_t gbp_pktbuffSize = 0;
#ifdef GBP_FEATURE_PARSE_PACKET_USE_DECOMPRESSOR
gbp_pkt_tileAcc_t tileBuff = { 0 };
#endif
#endif

#ifdef GBP_FEATURE_PARSE_PACKET_MODE
inline void gbp_parse_packet_loop();
#endif

/*******************************************************************************
  Utility Functions
*******************************************************************************/

const char* gbpCommand_toStr(int val) {
  switch (val) {
    case GBP_COMMAND_INIT: return "INIT";
    case GBP_COMMAND_PRINT: return "PRNT";
    case GBP_COMMAND_DATA: return "DATA";
    case GBP_COMMAND_BREAK: return "BREK";
    case GBP_COMMAND_INQUIRY: return "INQY";
    default: return "?";
  }
}

/*******************************************************************************
  Interrupt Service Routine using direct GPIO
*******************************************************************************/
void gpio_irq_callback(uint gpio, uint32_t events) {
  if (gpio == GBP_SC_PIN) {
    bool so_bit = gpio_get(GBP_SO_PIN);  // Read the bit from the master (SO = Serial Output from Master)
    bool tx_bit;
#ifdef GBP_FEATURE_USING_RISING_CLOCK_ONLY_ISR
    tx_bit = gpb_serial_io_OnRising_ISR(so_bit);
#else
    bool sc_level = gpio_get(GBP_SC_PIN);
    tx_bit = gpb_serial_io_OnChange_ISR(sc_level, so_bit);
#endif
    gpio_put(GBP_SI_PIN, tx_bit);  // Write the response bit back to the master
  }
}

/*******************************************************************************
  Main Setup and Loop
*******************************************************************************/

void setup(void) {
#ifdef DEBUG_MODE
  Serial.begin(115200);
#endif
  Tiny_printer_preparation();  //switches in Tiny Printer mode
  gpio_init(BTN_PUSH);         // Configure BTN_PUSH as input
  gpio_set_dir(BTN_PUSH, GPIO_IN);
  gpio_init(GBP_SC_PIN);  // Configure SC and SO as inputs too
  gpio_set_dir(GBP_SC_PIN, GPIO_IN);
  gpio_init(GBP_SO_PIN);
  gpio_set_dir(GBP_SO_PIN, GPIO_IN);
  gpio_init(GBP_SI_PIN);  // Configure SI as output
  gpio_set_dir(GBP_SI_PIN, GPIO_OUT);
  gpio_put(GBP_SI_PIN, 0);  // start LOW
  LED_WS2812_state(WS2812_Idle, 1);

  /* Setup */
  gpb_serial_io_init(sizeof(gbp_serialIO_raw_buffer), gbp_serialIO_raw_buffer);

  /* Attach ISR / Enable GPIO interrupt with callback */
#ifdef GBP_FEATURE_USING_RISING_CLOCK_ONLY_ISR
  gpio_set_irq_enabled_with_callback(GBP_SC_PIN, GPIO_IRQ_EDGE_RISE, true, &gpio_irq_callback);
#else
  gpio_set_irq_enabled_with_callback(GBP_SC_PIN, GPIO_IRQ_EDGE_RISE | GPIO_IRQ_EDGE_FALL, true, &gpio_irq_callback);
#endif

  /* Packet Parser */
#ifdef GBP_FEATURE_PARSE_PACKET_MODE
  gbp_pkt_init(&gbp_pktState);
#endif

#ifdef DEBUG_MODE
  Serial.println(F("// Game Boy Printer Emulator for Arduino " VERSION_STRING));
  Serial.println(F("// TinyGB Printer converter add-on " TINY_VERSION_STRING));
  Serial.flush();
#endif
}  // setup()

void loop() {
  static uint16_t sioWaterline = 0;

#ifdef GBP_FEATURE_PARSE_PACKET_MODE
  gbp_parse_packet_loop();
#endif

  // Trigger Timeout and reset the printer if byte stopped being received.
  static uint32_t last_millis = 0;
  uint32_t curr_millis = millis();
  if (curr_millis > last_millis) {
    uint32_t elapsed_ms = curr_millis - last_millis;
    if (gbp_serial_io_timeout_handler(elapsed_ms)) {
#ifdef DEBUG_MODE
      Serial.print("Core 0 -> ");
      Serial.print("Completed ");
      Serial.print("(Memory Waterline: ");
      Serial.print(gbp_serial_io_dataBuff_waterline(false));
      Serial.print("B out of ");
      Serial.print(gbp_serial_io_dataBuff_max());
      Serial.println("B)");
#endif
      gbp_pkt_reset(&gbp_pktState);
      tileBuff.count = 0;
      /////////////Specific to TinyGB Printer//////////////
      //incomplete packet due to abort command or transmission stopped inbetween DATA packets
      if (!(DATA_bytes_counter % 640 == 0) | (gbp_pktState.command == GBP_COMMAND_DATA)) {
#ifdef DEBUG_MODE
        Serial.println("Core 0 -> Incomplete packet detected due to abort command, flush printer");
#endif
        SD.remove(tmp_storage_file_name);  //remove any previous failed attempt
        lines_in_image_file = 0;           //resets the number of lines
        DATA_bytes_counter = 0;            //reset
        DATA_packet_counter = 0;           //reset
        DATA_packet_to_print = 0;          //reset
        LED_WS2812_state(WS2812_Idle, 1);
      }
      /////////////Specific to TinyGB Printer//////////////
      Serial.flush();
    }
  }
  last_millis = curr_millis;
}  // loop()

/////////////Specific to TinyGB Printer//////////////
void loop1()  //core 1 loop deals with images, written by Raphaël BOICHOT, november 2024
{
  if (PRINT_flag == 1) {
    PRINT_flag = 0;
    if (DATA_bytes_to_print == 320) {  //fix for Blarble 1290 homebrew, only game using "half packets", not supported by default
      memcpy(printer_memory_buffer_core_1, printer_memory_buffer_core_0, 320);
    } else {                                                                                           //regular game, packets are 640 bytes long, 40 tiles, 16 pixels height
      memcpy(printer_memory_buffer_core_1, printer_memory_buffer_core_0, 640 * DATA_packet_to_print);  //this can also be done by core 0
    }
    LED_WS2812_state(WS2812_Color, 1);
    if (inner_palette == 0x00) {  //4 games uses this palette
      inner_palette = 0xE4;       //see Game Boy Programming manual, palette 0x00 is a default palette interpreted as 0xE4 or 0b11100100
#ifdef DEBUG_MODE
      Serial.println("Core 1 -> Palette 0x00, fixed to 0xE4");
#endif
    }
    if (inner_palette == 0xE1) {  //1 game uses this wrong palette
      inner_palette = 0xD2;       //palette fix for Disney's Tarzan, inverts DG and LG
#ifdef DEBUG_MODE
      Serial.println("Core 1 -> Palette 0xE1 (Disney's Tarzan), fixed to 0xD2");
#endif
    }
    if (inner_palette == 0x2D) {  //1 game uses this wrong palette
      inner_palette = 0x1E;       //palette fix for Trade & Battle: Card Hero, inverts DG and LG. Text will become hard to read but at least creatures are well depicted
#ifdef DEBUG_MODE
      Serial.println("Core 1 -> Palette 0x2D (Trade & Battle: Card Hero), fixed to 0xE1");
#endif
    }
    //0xE4 = 0b11100100 = 3-2-1-0 intensity of colors for printer (3 = black, 0 = white), for Game Boy pixel encoded values 0-1-2-3
    image_palette[0] = bitRead(inner_palette, 0) + 2 * bitRead(inner_palette, 1);
    image_palette[1] = bitRead(inner_palette, 2) + 2 * bitRead(inner_palette, 3);
    image_palette[2] = bitRead(inner_palette, 4) + 2 * bitRead(inner_palette, 5);
    image_palette[3] = bitRead(inner_palette, 6) + 2 * bitRead(inner_palette, 7);

#ifdef DEBUG_MODE
    Serial.print("Core 1 -> I received ");
    Serial.print(DATA_packet_to_print, DEC);
    Serial.print(" packets to print with palette ");
    Serial.print(inner_palette, HEX);
    Serial.print(" and ");
    Serial.print(inner_lower_margin, DEC);
    Serial.println(" after margin");
#endif

    //All the meat to decode the 2bpp Game Boy Tile Format is explained here (among other sources): https://www.huderlem.com/demos/gameboy2bpp.html
    //the image data are a simple one dimensional array because there is no gain to have a 2D array, in particular when burning data to SD card
    //the issue here is to transform a tile-based system (8*8 pixels) to a pixel-based system in lines/columns.
    //we convert image as a whole, not packet per packet (no need)
    IMAGE_bytes_counter = 0;
    pixel_line = 0;
    offset_x = 0;

    if (DATA_bytes_to_print == 320) {  //fix for Blarble 1290 homebrew, only game using "half packets", not supported by default
      max_tile_line = 1;               //a DATA packet is 2 tiles high
      max_pixel_line = 8;              //a DATA packet is 16 pixel high
    } else {
      max_tile_line = DATA_packet_to_print * 2;    //a DATA packet is 2 tiles high
      max_pixel_line = DATA_packet_to_print * 16;  //a DATA packet is 16 pixel high
    }

    for (tile_line = 0; tile_line < max_tile_line; tile_line++) {                  //this part fills 8 lines of pixels
      IMAGE_bytes_counter = 16 * 20 * tile_line;                                   //a tile is 16 bytes, a line screen is 20 tiles (160 pixels width)
      for (int i = 0; i < 8; i++) {                                                // This part fills a line of pixels
        offset_x = pixel_line * 160;                                               //x stands for the position in the image vector containing compressed data
        for (tile_column = 0; tile_column < 20; tile_column++) {                   //we progress along 20 column tiles
          local_byte_LSB = printer_memory_buffer_core_1[IMAGE_bytes_counter];      //here we get data for a line of 8 pixels (2 bytes)
          local_byte_MSB = printer_memory_buffer_core_1[IMAGE_bytes_counter + 1];  //here we get data for a line of 8 pixels
          for (int posx = 0; posx < 8; posx++) {
            pixel_level = bitRead(local_byte_LSB, 7 - posx) + 2 * bitRead(local_byte_MSB, 7 - posx);  //here we get pixel value along 8 pixels horizontally
            PNG_image_color[offset_x + posx] = PNG_compress_4x[image_palette[pixel_level]];           //here we store 4 2bbp pixels per byte for next step (2bpp indexed png upscaler)
          }                                                                                           //this is a bit aggressive as pixel decoder and PNG compression is within the same line of code, but efficient
          IMAGE_bytes_counter = IMAGE_bytes_counter + 16;                                             //jumps to the next tile in byte
          offset_x = offset_x + 8;                                                                    //jumps to the next tile in pixels
        }                                                                                             //This part fills a line of pixels
        IMAGE_bytes_counter = IMAGE_bytes_counter - 16 * 20 + 2;                                      //shifts to the next two bytes among 16 per tile, so the next line of pixels in a tile
        pixel_line = pixel_line + 1;                                                                  //jumps to the next line
      }                                                                                               //This part fills 8 lines of pixels
    }                                                                                                 //this part fills the entire image

    if ((TEAR_mode == 0) && (inner_lower_margin > 0)) {  //just to make a fancy display with clear image separation
      max_pixel_line = max_pixel_line + TFT_offset;
    }

    //the TFT diplay can hold 15 data packets simultaneously
    //Step 1: copy previous data with a vertical upper translation corresponding to future printing area
    for (int x = 0; x < 160; x++) {
      for (int y = max_pixel_line; y < 240; y++) {
        TFT_memory_buffer[x + (y - max_pixel_line) * 160] = TFT_memory_buffer[x + y * 160];
      }
    }
    //Step 2: print the new image data after the previous ones at the bottom of display area
    for (int x = 0; x < 160; x++) {
      for (int y = 0; y < max_pixel_line; y++) {
        TFT_memory_buffer[x + (240 - max_pixel_line + y) * 160] = 0xFF - PNG_image_color[x + y * 160];  //color are inverter compared to the PNG format
      }
    }

    if ((TEAR_mode == 0) && (inner_lower_margin > 0)) {  //just to make a fancy display with clear image separation
      //Step 3: overwite the end of buffer with cool pixels
      for (int x = 0; x < 160; x++) {
        for (int y = 0; y < TFT_offset; y++) {
          TFT_memory_buffer[x + (y + 240 - TFT_offset) * 160] = tearsymbol[x + y * 160];
        }
      }
    }

    //converts tft buffer into a giant sprite covering a whole strip
    for (int x = 0; x < 160; x++) {
      for (int y = 0; y < 240; y++) {
        img.drawPixel(x, y, lookup_TFT_RGB565[TFT_memory_buffer[x + y * 160]]);
      }
    }
    img.pushSprite(x_ori, 0);  //dump image to display

    File Datafile = SD.open(tmp_storage_file_name, FILE_WRITE);  //in any case, if PRINT is received, write to a file (yet existing or not)
    if (DATA_bytes_to_print == 320) {                            //fix for Blarble 1290 homebrew, only game using "half packets", not supported by default
      Datafile.write(PNG_image_color, 160 * 8);                  //writes half the data to SD card
    } else {
      Datafile.write(PNG_image_color, 160 * 16 * DATA_packet_to_print);  //writes the data to SD card
    }
    Datafile.close();

    if (DATA_bytes_to_print == 320) {                 //fix for Blarble 1290 homebrew, only game using "half packets", not supported by default
      lines_in_image_file = lines_in_image_file + 8;  //keep track of the number of lines stored
    } else {
      lines_in_image_file = lines_in_image_file + 16 * DATA_packet_to_print;  //keep track of the number of lines stored
    }
    DATA_packet_to_print = 0;

    if ((inner_lower_margin > 0) & (TEAR_mode == 0)) {  //the printer asks to feed paper, end of file, except in TEAR mode
      Next_ID++;                                        //increment file number
      store_next_ID("/tiny.sys", Next_ID, Next_dir);
      sprintf(png_storage_file_name, "/%05d/%07d.png", Next_dir, Next_ID);
#ifdef DEBUG_MODE
      Serial.print("Core 1 -> Encoding ");
      Serial.print(png_storage_file_name);
      Serial.print(" due to feed paper signal, with ");
      Serial.print(lines_in_image_file, DEC);
      Serial.println(" lines in image file");
#endif
      myTime = millis();
      png_upscaler(tmp_storage_file_name, png_storage_file_name, PNG_palette_RGB, lines_in_image_file);
#ifdef DEBUG_MODE
      Serial.print("Core 1 -> PNG file closed, encoding time (ms): ");
      Serial.println(millis() - myTime, DEC);
#endif
      FILE_number = FILE_number + 1;
#ifdef DEBUG_MODE
      Serial.print("Core 1 -> Number of file for this session: ");
      Serial.println(FILE_number, DEC);
#endif
      if (BITBOY_mode == 0) {  // in this mode the folders are incremented at each boot
        if (FILE_number % max_files_per_folder == 0) {
          Next_dir++;
          store_next_ID("/tiny.sys", Next_ID, Next_dir);  //store next folder #immediately
        }
      } else {  // in this mode the folders must contain 100 files
        if ((Next_ID % 100) == 0) {
          Next_dir++;
          store_next_ID("/tiny.sys", Next_ID, Next_dir);  //store next folder #immediately
        }
      }

      lines_in_image_file = 0;           //resets the number of lines
      SD.remove(tmp_storage_file_name);  //a bit aggressive and maybe not optimal but I'm sure the old data disappears
    }
    LED_WS2812_state(WS2812_Idle, 1);
  }

  //in TEAR mode, a file is never closed unless you push a button
  if ((TEAR_mode == 1) & (gpio_get(BTN_PUSH)) & (lines_in_image_file > 0)) {  //in tear mode, a button push only can close file, whatever the printer (non empty) state
    LED_WS2812_state(WS2812_Color, 1);
    Next_ID++;  //increment file number
    store_next_ID("/tiny.sys", Next_ID, Next_dir);
    sprintf(png_storage_file_name, "/%05d/%07d.png", Next_dir, Next_ID);
#ifdef DEBUG_MODE
    Serial.print("Core 1 -> Encoding ");
    Serial.print(png_storage_file_name);
    Serial.print(" due to push button, with ");
    Serial.print(lines_in_image_file, DEC);
    Serial.println(" lines in image file");
#endif
    myTime = millis();
    png_upscaler(tmp_storage_file_name, png_storage_file_name, PNG_palette_RGB, lines_in_image_file);
#ifdef DEBUG_MODE
    Serial.print("Core 1 -> PNG file closed, encoding time (ms): ");
    Serial.println(millis() - myTime, DEC);
#endif
    FILE_number = FILE_number + 1;
#ifdef DEBUG_MODE
    Serial.print("Core 1 -> Number of file for this session: ");
    Serial.println(FILE_number, DEC);
#endif

    if (BITBOY_mode == 0) {
      if (FILE_number % max_files_per_folder == 0) {
        Next_dir++;
        store_next_ID("/tiny.sys", Next_ID, Next_dir);  //store next folder #immediately
      }
    } else {
      if ((Next_ID % 100) == 0) {
        Next_dir++;
        store_next_ID("/tiny.sys", Next_ID, Next_dir);  //store next folder #immediately
      }
    }

    lines_in_image_file = 0;           //resets the number of lines
    SD.remove(tmp_storage_file_name);  //a bit aggressive and maybe not optmal but I'm sure the old data disappears

    memset(TFT_memory_buffer, 255, sizeof(TFT_memory_buffer));  //clears the image buffer
    img.fillScreen(TFT_WHITE);                                  //clears the display
    img.pushSprite(x_ori, 0);                                   //dumps white image to display

    LED_WS2812_state(WS2812_Idle, 1);
  }
}  // loop1()
/////////////Specific to TinyGB Printer//////////////
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

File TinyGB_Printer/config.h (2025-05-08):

/****************************************
 * SD CARD MODULE DEFINITIONS FOR PI PICO
 ****************************************/
//    SD card attached to SPI bus as follows on RP2040:
//   ************ SPI0 ************
//   ** MISO (AKA RX) - pin 0, 4, or 16
//   ** MOSI (AKA TX) - pin 3, 7, or 19
//   ** CS            - pin 1, 5, or 17
//   ** SCK           - pin 2, 6, or 18
//   ************ SPI1 ************
//   ** MISO (AKA RX) - pin  8 or 12
//   ** MOSI (AKA TX) - pin 11 or 15
//   ** CS            - pin  9 or 13
//   ** SCK           - pin 10 or 14

#define SD_MISO 8    // SD card SPI1
#define SD_CS 9      // SD card SPI1
#define SD_SCK 10    // SD card SPI1
#define SD_MOSI 11   // SD card SPI1
#define BTN_PUSH 12  // Define a PushButton to use to Force a new file in idle mode ///BOICHOT
#define VERSION_STRING "V3.2.1 (Copyright (C) 2022 Brian KHUU)"
#define TINY_VERSION_STRING "V2.0.4 (Copyright (C) 2024 Raphaël BOICHOT)"
#define TINY_VERSION_SHORT "V2.0.4"
bool BITBOY_mode = 0;  //mimicks the folder strategy of the BitBoy (100 files per folder)
//#define DEBUG_MODE   //allow additionnal outputs on on serial, only for debugging

/* Gameboy Link Cable Mapping to Arduino Pin */
// Note: Serial Clock Pin must be attached to an interrupt pin of the arduino
//  ___________
// |  6  4  2  |
//  \_5__3__1_/   (at cable)
//
#define GBP_SO_PIN 4       // Cable pin 2 : Serial OUTPUT
#define GBP_SI_PIN 3       // Cable pin 3 : Serial INPUT
#define GBP_SC_PIN 2       // Cable pin 5 : Serial Clock (Interrupt)
#define LED_STATUS_PIN 16  // Internal LED blink on packet reception
#define NUMPIXELS 1        // NeoPixel ring size (just internal LED here)
Adafruit_NeoPixel pixels(NUMPIXELS, LED_STATUS_PIN, NEO_RGB);
uint8_t intensity = 60;                                    //WS2812 intensity 255 is a death ray, 10 to 15 is normal
uint32_t WS2812_Color = pixels.Color(0, intensity, 0);     //RGB triplet, default is green, turns to blue in tear mode
uint32_t WS2812_SD_crash = pixels.Color(intensity, 0, 0);  //RGB triplet, turn to red, issue with SD card
uint32_t WS2812_Idle = pixels.Color(1, 1, 1);              //RGB triplet, turn to cyan, device idle

//Offset for the 240*240 ST7789 display
#define x_ori 40
#define BITS_PER_PIXEL 16
//grayscale 8 bits table to RGB565
const unsigned short int lookup_TFT_RGB565[256] = { 0x0000, 0x0000, 0x0000, 0x0000, 0x0020, 0x0020, 0x0020, 0x0020, 0x0841, 0x0841, 0x0841, 0x0841, 0x0861, 0x0861, 0x0861, 0x0861,
                                                    0x1082, 0x1082, 0x1082, 0x1082, 0x10A2, 0x10A2, 0x10A2, 0x10A2, 0x18C3, 0x18C3, 0x18C3, 0x18C3, 0x18E3, 0x18E3, 0x18E3, 0x18E3,
                                                    0x2104, 0x2104, 0x2104, 0x2104, 0x2124, 0x2124, 0x2124, 0x2124, 0x2945, 0x2945, 0x2945, 0x2945, 0x2965, 0x2965, 0x2965, 0x2965,
                                                    0x3186, 0x3186, 0x3186, 0x3186, 0x31A6, 0x31A6, 0x31A6, 0x31A6, 0x39C7, 0x39C7, 0x39C7, 0x39C7, 0x39E7, 0x39E7, 0x39E7, 0x39E7,
                                                    0x4208, 0x4208, 0x4208, 0x4208, 0x4228, 0x4228, 0x4228, 0x4228, 0x4A49, 0x4A49, 0x4A49, 0x4A49, 0x4A69, 0x4A69, 0x4A69, 0x4A69,
                                                    0x528A, 0x528A, 0x528A, 0x528A, 0x52AA, 0x52AA, 0x52AA, 0x52AA, 0x5ACB, 0x5ACB, 0x5ACB, 0x5ACB, 0x5AEB, 0x5AEB, 0x5AEB, 0x5AEB,
                                                    0x630C, 0x630C, 0x630C, 0x630C, 0x632C, 0x632C, 0x632C, 0x632C, 0x6B4D, 0x6B4D, 0x6B4D, 0x6B4D, 0x6B6D, 0x6B6D, 0x6B6D, 0x6B6D,
                                                    0x738E, 0x738E, 0x738E, 0x738E, 0x73AE, 0x73AE, 0x73AE, 0x73AE, 0x7BCF, 0x7BCF, 0x7BCF, 0x7BCF, 0x7BEF, 0x7BEF, 0x7BEF, 0x7BEF,
                                                    0x8410, 0x8410, 0x8410, 0x8410, 0x8430, 0x8430, 0x8430, 0x8430, 0x8C51, 0x8C51, 0x8C51, 0x8C51, 0x8C71, 0x8C71, 0x8C71, 0x8C71,
                                                    0x9492, 0x9492, 0x9492, 0x9492, 0x94B2, 0x94B2, 0x94B2, 0x94B2, 0x9CD3, 0x9CD3, 0x9CD3, 0x9CD3, 0x9CF3, 0x9CF3, 0x9CF3, 0x9CF3,
                                                    0xA514, 0xA514, 0xA514, 0xA514, 0xA534, 0xA534, 0xA534, 0xA534, 0xAD55, 0xAD55, 0xAD55, 0xAD55, 0xAD75, 0xAD75, 0xAD75, 0xAD75,
                                                    0xB596, 0xB596, 0xB596, 0xB596, 0xB5B6, 0xB5B6, 0xB5B6, 0xB5B6, 0xBDD7, 0xBDD7, 0xBDD7, 0xBDD7, 0xBDF7, 0xBDF7, 0xBDF7, 0xBDF7,
                                                    0xC618, 0xC618, 0xC618, 0xC618, 0xC638, 0xC638, 0xC638, 0xC638, 0xCE59, 0xCE59, 0xCE59, 0xCE59, 0xCE79, 0xCE79, 0xCE79, 0xCE79,
                                                    0xD69A, 0xD69A, 0xD69A, 0xD69A, 0xD6BA, 0xD6BA, 0xD6BA, 0xD6BA, 0xDEDB, 0xDEDB, 0xDEDB, 0xDEDB, 0xDEFB, 0xDEFB, 0xDEFB, 0xDEFB,
                                                    0xE71C, 0xE71C, 0xE71C, 0xE71C, 0xE73C, 0xE73C, 0xE73C, 0xE73C, 0xEF5D, 0xEF5D, 0xEF5D, 0xEF5D, 0xEF7D, 0xEF7D, 0xEF7D, 0xEF7D,
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

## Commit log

2024-11-08 RP2040 button definition, not reported to main code
2024-11-12 Support for the WS2812 LED added + autonomous
2024-11-18 BMP decoder working but some glitches remain
    [TinyGB_Printer.ino, config.h]
2024-11-22 Now device outputs 4x PNG natively
2024-12-02 Corrects a possible buffer overflow
    [TinyGB_Printer.ino, config.h]
2024-12-12 Cyan led color for indicating idle state
2024-12-12 White LED to signal that device is alive
2024-12-12 Idle state = white LED
2025-01-04 SD failure message and display rotation
    [TinyGB_Printer.ino]
2025-02-19 3D printed enclosure by Slade1972
    [GBPrinter - Base.step, GBPrinter - Base.stl, GBPrinter - Button.step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]
2025-05-07 pi pico SDK for interrupts and I/O
2026-01-12 Update README with TinyGB Printer details and fun facts
    Clarified details about the TinyGB Printer's features, reliability, and display specifications. Added notes on serial port schematics and printing behavior of games.
2026-01-12 Update README with batteryless operation instructions
    Added warning about using third-party cables and running the device on Game Boy models.
2026-01-12 Update README with diode usage and connection details
    Clarified instructions for using a Shottky diode and provided additional guidance for post-assembly connections.
